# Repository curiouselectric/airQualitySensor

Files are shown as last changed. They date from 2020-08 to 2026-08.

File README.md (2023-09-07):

# airQualitySensor
This is a PCB and design for an air quality sensor unit using the [sensor.community](https://maps.sensor.community/) design

This is a PCB design (in KiCAD) and laser cut enclosure plate design to make an air quality sensor node for inclusion in the [sensor.community](https://maps.sensor.community/) global open environmental data platform .
I think the project is amazing and produced this design for a simplified, but robust DIY kit.

This is heavily based on these two open-source projects:

https://github.com/CivicLabsBelgium/influencair-pcb

https://github.com/Naesstrom/Airrohr-kit

The second link (by Erik Näsström) is a great design. I wanted to, very slightly, simplify this and produce a unit that does not need a 3d printer. I set about designing laser cut parts for this.

The PCB is very simple, but has been produced in the totally open-source PCB design package KiCAD.

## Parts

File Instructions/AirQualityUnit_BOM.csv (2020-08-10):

Reference | Item | Quantity | Value
C1 | Power supply buffer capacitor | 1 | 220uf
J1 | 2.1mm barrel jack power connector | 1 | 5V
J2 | 2 way screw terminal | 1 | 5V
J3 | ADC input pins | 0 | ADC_IN
J4 | ADS1115 ADC connector. NOT supplied! | 0 | ADS1115_ADC
J8 | Temperature and Humidity Sensor | 1 | BME280
J9 | 4 way Connector - Grove Wiring. NOT supplied! | 0 | I2C_1
J10 | 4 way Connector - Grove Wiring. NOT supplied! | 0 | I2C_2
J11 | 4 way Connector - Grove Wiring. NOT supplied! | 0 | I2C_3
J12 | Temperature and Humidity Sensor. NOT supplied! | 0 | DHT22
J13 | 5Way JST-XH 90 Connector for: Dust and particle sensor. | 1 | SDS011
J14,J15 | 15 way Header for NodeMCU | 2 | ESP_BO1, ESP_BO2
P1 | SMD USB connector. NOT supplied! | 0 | PWR
R1 | Used if DHT22 sensor used. NOT supplied! | 0 | 4k7
U1 | Programmed NodeMCU ESP8266 Unit. | 1 | NODEMCU
PCB | Circuit board for all sensors. | 1
SDS011 | Dust and Particle sensor | 1
USB Power Lead | 5m USB cable. | 1
Wire | 4 colours for connecting BME280 to PCB. | 4
Enclosure | Waterproof small encosure. Pre-cut holes. | 1
Baseplate | Laser Cut | 1
Rubber Seal | Laser Cut | 1
Side Plate | Laser Cut | 1
Insect Mesh | Small piece | 1
Gromit | For USB power lead | 1
Pipe | Small Pipe ID: 6mm OD 8mm - yellow | 1
Spacers 3mm | Hold SDS to PCB | 3
Spacers 20mm | Hold SDS to baseplate | 3
M3 screws 10mm | Hold PCB and Baseplate | 6
Self Tapping screws | Hold baseplate to enclosure | 4
M3 screws 20mm | Hold rubber seal and side plate | 4
M3 Nuts | Hold rubber seal and side plate | 4
M2 screws 20mm | Hold BME280 in place | 2
M2 Nuts | Hold BME280 in place | 2

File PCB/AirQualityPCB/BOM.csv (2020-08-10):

Reference | Value | Footprint | Datasheet
U1 | NODEMCU | REInnovationFootprint:NodeMCU_Amica_R2_FSILK
J13 | SDS011 | REInnovationFootprint:SIL-5_JST_5WAY_labelled | ~
J8 | BME280 | REInnovationFootprint:SIL-4_large_pad_BME280 | ~
J1 | 5V | REInnovationFootprint:DC_Power_2_1 | ~
J2 | 5V | REInnovationFootprint:SIL-2_screw_terminal | ~
P1 | PWR | REInnovationFootprint:USB_Micro-B_MOLEX_47642-0001
J5 | PCB | REInnovationFootprint:PCB_LuftDaten_70x70 | ~
J6 | LOGO_OSW | REInnovationFootprint:OSHW_logo_small_back | ~
J7 | LOGO_TCEC | CuriousElectric3:TCEC_Words_13mm | ~
J9 | I2C_1 | REInnovationFootprint:SIL-4_Grove_Labelled | ~
J11 | I2C_3 | REInnovationFootprint:SIL-4_Grove_Labelled | ~
J10 | I2C_2 | REInnovationFootprint:SIL-4_Grove_Labelled | ~
R1 | 4k7 | REInnovationFootprint:TH_Resistor_1 | ~
J12 | DHT22 | REInnovationFootprint:SIL-4_large_pad_DHT22 | ~
J4 | ADS1115_ADC | REInnovationFootprint:ADAFRUIT_ADS1115 | ~
J14 | ESP_BO1 | Connector_PinSocket_2.54mm:PinSocket_1x15_P2.54mm_Vertical | ~
J15 | ESP_BO2 | Connector_PinSocket_2.54mm:PinSocket_1x15_P2.54mm_Vertical | ~
J16 | LOGO_LUFTDATEN | CuriousElectric3:sensorcommunity | ~
J17 | LOGO_AirRohr | CuriousElectric3:logo_conversion | ~
J18 | LOGO_TCEC | CuriousElectric3:2019_011_16_CuriousElectricCompany_Logo_Round_Logo_No_words_KiCAD_10mm_PCBLogo | ~
C1 | 100uf | REInnovationFootprint:C_Radial_D6.3_L11.2_P2.5 | ~
J3 | ADC_IN | REInnovationFootprint:PinSocket_1x12_P2.54mm_Vertical_Labelled | ~

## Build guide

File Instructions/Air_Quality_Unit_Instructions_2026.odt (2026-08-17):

| Air Quality Unit Build Instructions

Date: | 17/09/2026 | Version: | 1.3 | By: | Matt Little

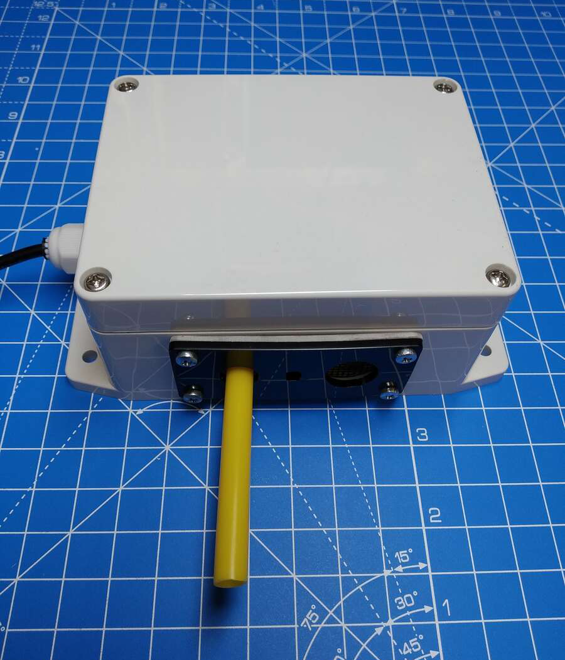
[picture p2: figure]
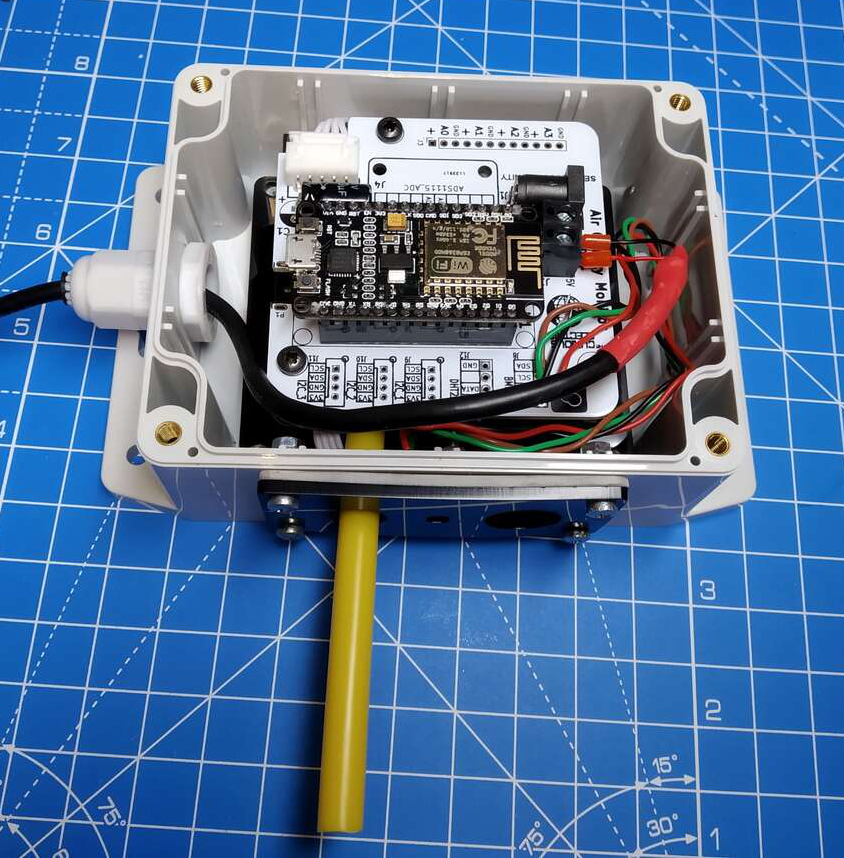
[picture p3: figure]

Build your own air quality monitor and contribute to the https://maps.sensor.community worldwide air quality monitoring project. Civil Tech in action!

This kit contains all you need to set up your own online air quality monitoring unit. This records the PM2.5 and PM10 particulate data, along with temperature and humidity. This is sent (via your Wi-Fi connection) to the sensor.community platform.

In building and installing this equipment you are helping monitor local and global air quality and provide results to a growing network of civil technology sensor units!

The unit uses the SDS011 dust and particulate sensor, along with a BME280 temperature and humidity sensor. These are interfaced with an ESP8266 Wi-Fi enabled microcontroller.

Additional PCB connections can be made to add more sensors in the future.

Note: This kit contains all hardware required to set up your sensor unit. You will need a local wifi connection. You will need to install in a location which can connect to that network.

This kit requires soldering, some hardware construction and setting up an online sensor.community account and sensor node. This should take in the region of 2-4 hours to build.

This kit relies upon the sensor.community platform. Curious Electric use their firmware and do not have any input to the software side of the project.

Parts included:

| | Baseplate | 4 x self-tapping screws | | PCB | SDS011 Dust Sensor

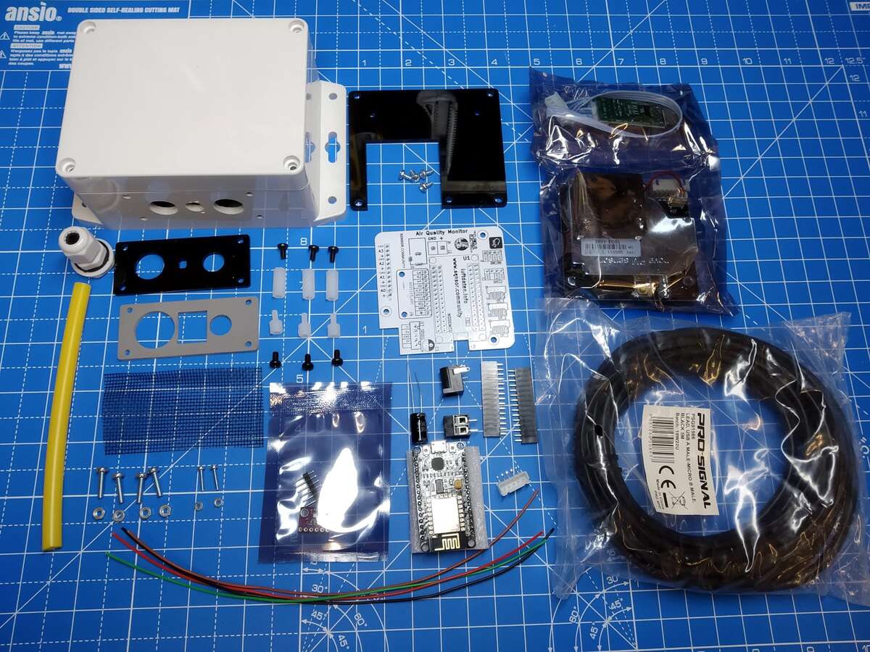
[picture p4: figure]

Enclosure (pre-cut holes)
| | | | | | | | Power Jack
| | | | | | | | 2 x 15way Header Pins
Compression Gland
Sensor Plate | | | | | | | | 220uf Capacitor
| | | | | | | | Screw Terminals
Rubber Gasket | | | | | | | | USB lead (5m)
M3 Hex Spacers: 3 x 6mm & 3 x 15mm
6 x M3 6mm screws | | | | | | | | 5 Way JST-XH Socket
8mm Pipe | M3 fixings 12mm x 4 | M2.5 fixings 12mm x 2 | | Mesh | BME280 (in bag – pins not needed) | Node MCU (ESP2866)

Parts list:

Item | Ref | | Item | Ref
Power supply buffer capacitor. 220uf | C1 | | Dust and Particle sensor | SDS011
2.1mm barrel jack power connector | J1 | | 5m USB cable. | USB Power Lead
2 way screw terminal | J2 | | Waterproof small enclosure. Pre-cut holes. | Enclosure
ADC input pins NOT supplied/needed! | J3 | | Laser Cut | Baseplate
ADS1115 ADC connector. NOT supplied! | J4 | | Laser Cut | Rubber Seal
BME280. Temperature and Humidity Sensor | J8 | | Laser Cut | Side Plate
4 way Connector - Grove Wiring. NOT supplied! | J9, J10, J11 | | Small piece | Insect Mesh
Temperature and Humidity Sensor. NOT supplied! | J12 | | For USB power lead | Compression Gland
5 Way JST-XH 90 Connector for SDS sensor. | J13 | | Small piece of Pipe 6mm OD 8mm - yellow | Pipe
2 x 15 way Header for NodeMCU | J14, J15 | | Hold SDS011 sesnsor to PCB. M3 Hex Spacers. | 3 x Hex Spacers 6mm
SMD USB connector. NOT supplied! | P1 | | Hold SDS011 sesnsor to PCB. M3 Hex Spacers. | 3 x Hex Spacers 15mm
4k7 ohm. For DHT22 sensor. NOT supplied! | R1 | | Hold PCB and Baseplate | 6 x M3 screws 6mm
NodeMCU ESP8266 Unit. Programmed with airRohr software. | U1 | | Hold baseplate to enclosure | Self Tapping screws
Printed Circuit Board. | PCB | | Hold rubber seal and side plate | 4 x M3 screws 12mm
4 x colour cable for connecting BME280 to PCB. 10cm long. | Cable | | Hold rubber seal and side plate | 4 x M3 Nuts
240V AC UK Plug USB PSU 1.2A | PSU | | Hold BME280 in place | 2 x M2.5 screws 12mm
| | | Hold BME280 in place | 2 x M2.5 Nuts

Tools required:

You may also need some scissors.

Hardware Instructions:

Step: 1 | Solder PCB

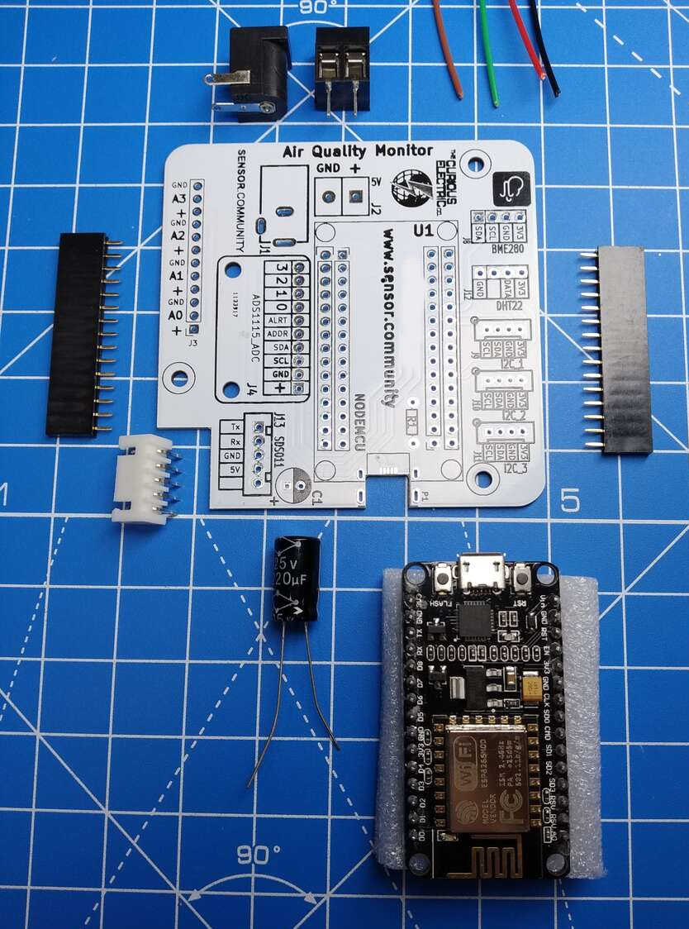
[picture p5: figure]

First we need to solder the components to the printed circuit board (PCB).

There are 6 components and 4 wires to solder.

Note: J1, J2 and J13 need to be pointing away from the edge of the PCB when fitted.

Fit J1 (barrel jack socket) and solder.

Fit J2 (screw terminals) and solder.

Fit J13 (JST-XH 5 way right angle connector) and solder.

Fit the two rows of header pins onto the pins of the NodeMCU. This can then be put in the holes marked for U1.

Check the orientation of the NodeMCU – the USB port should be towards the edge of the PCB.

The header pins can then be soldered to the PCB. Using the NodeMCU during soldering keeps the pins in place.

Next solder the polarised capacitor. Ensure correct orientation of these components.

The negative lead on the capacitor is marked with a white strip. The positive lead is slightly longer than the negative. Align the positive lead with the + sign and the negative lead with the black PCB marking.

Value | Ref | Marking
220uf Capacitor | C1 | 25V 220uf

This component is put into position then bent to lie flat on the PCB. Then solder it. This is required to ensure the lid fits on the enclosure.

Ensure sockets are point away from the edge of the PCB, as the cables will enter from the edge.

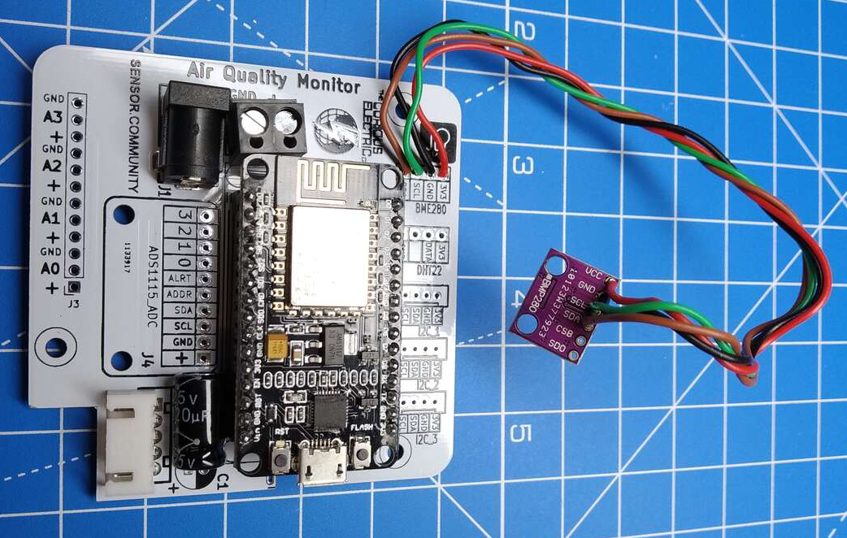
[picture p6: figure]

Using the four wires we need to solder the main PCB and connect to the BME280 sensor. Solder these wires so they come out on the labelled side of the sensor (as per photo).

Ensure USB pointing out, towards the PCB edge

There are four connections to make:

PCB BME280

+3.3V – Use Red wire. - VCC

GND – Use Black wire. - GND

SDA – Use either colour. - SDA

SCL – Use either colour. - SCL

The BME280 PCB is labelled with the same connections. Solder the matching names to the BME280.

Step: 2 | Add spacers to dust sensor

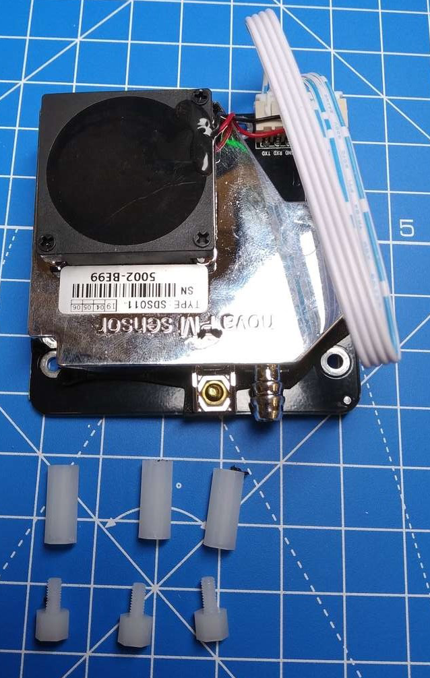
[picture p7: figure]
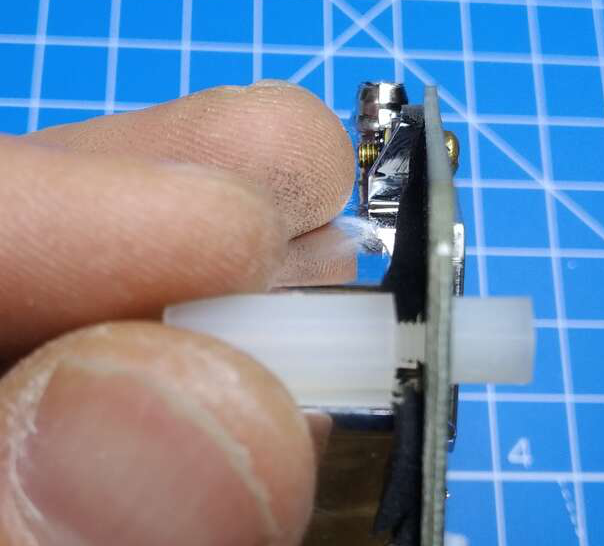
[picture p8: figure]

Take the SDS011 unit and cable from its package. (Note: There is a USB to serial converter in the package, if you would like to directly connect to the sensor from a computer, but that is not needed for this project) Use the 3 x 6mm M3 hex spacers (with thread sticking out) and the 3 x 15mm M3 hex spacers and connect through the three mouthing holes on the dust sensor. The longer (15mm) hex spacers should go on the side with the sensor (shiny box and fan), while the shorter spacers go on the PCB side of the sensor.

Step: 3 | Mount sensor to baseplate.

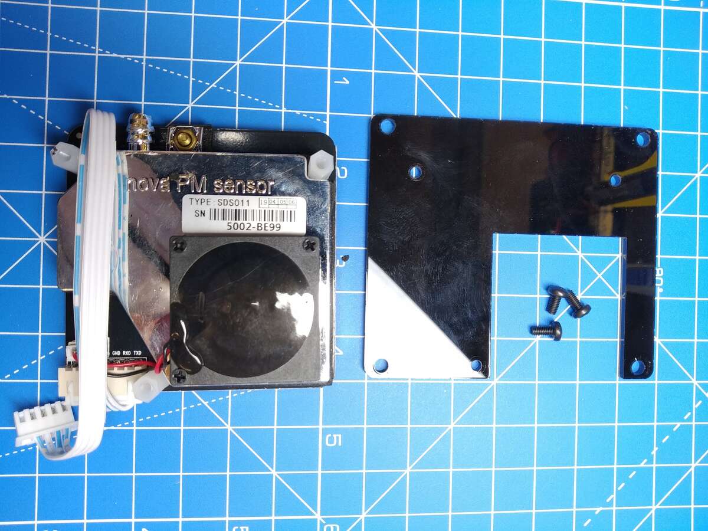
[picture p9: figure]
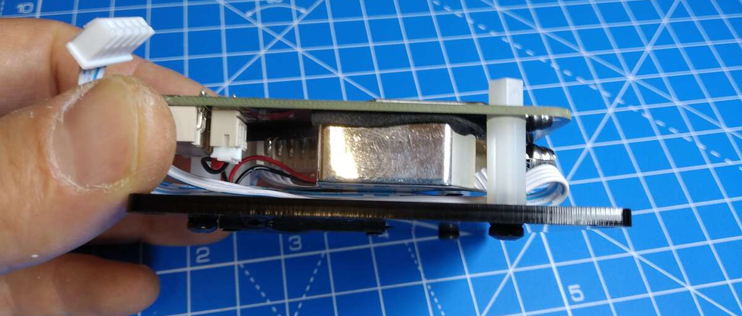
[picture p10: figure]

| | The SDS011 is mounted on the baseplate with the 20mm spacers towards the baseplate. The fan fits into the cut-out of the baseplate. Use 3 x M3 6mm machine screws to hold the sensor to the baseplate.

Step: 4 | Mount PCB to Sensor

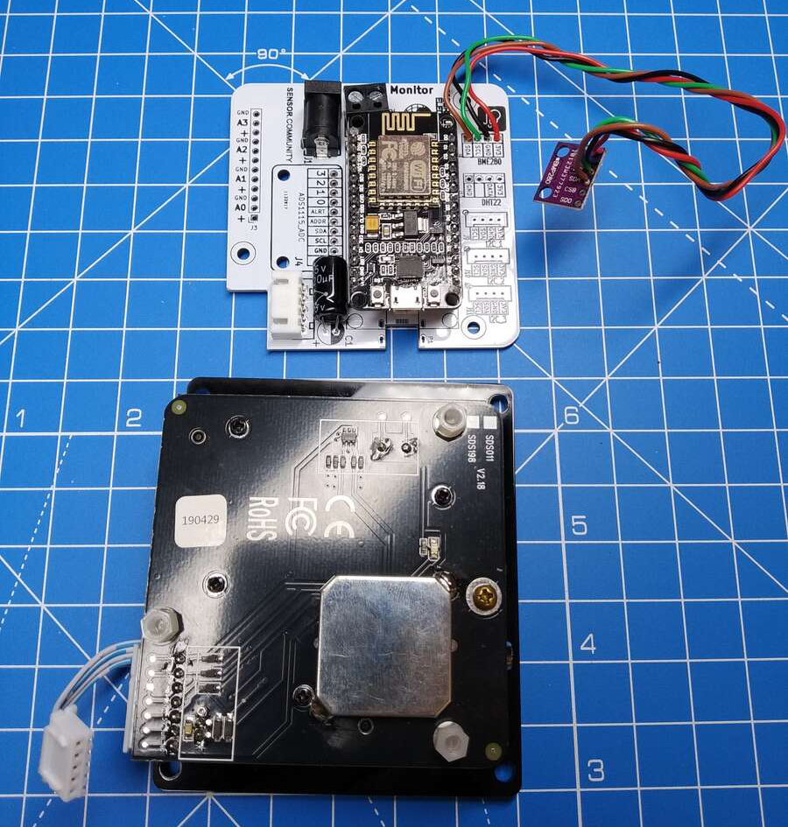
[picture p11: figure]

Mount the PCB to the top of the sensor. Use 3 of the M3 6mm machine screws to hold the PCB to the shorter hex spacers on the sensor. Use the white cable that comes with the SDS011 dust sensor to the PCB. The cable might need to be folded under to keep it out of the way.

Step: 5 | Add compression gland

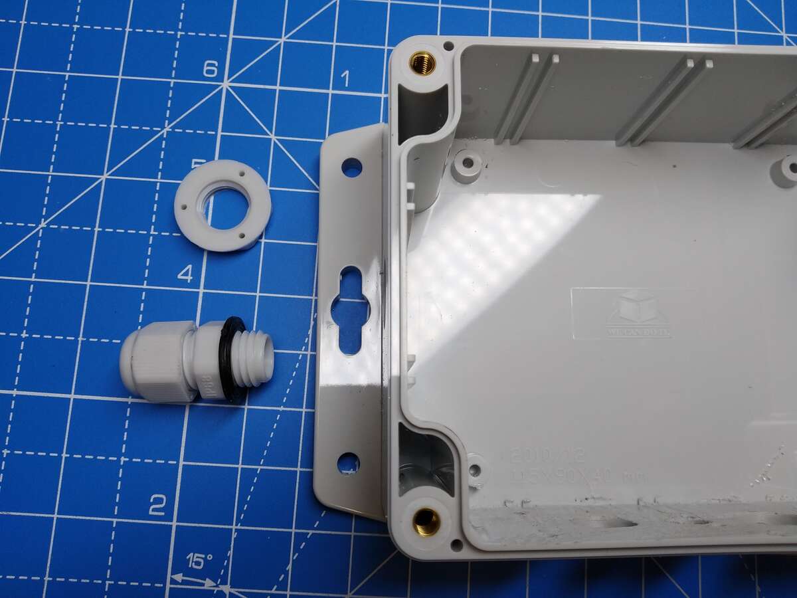
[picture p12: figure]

| | Mount the compression gland through the hold on the side of the enclosure. The enclosure is slightly thick for the gland, but if the nut is turned around, so the wide lip faces away from the gland, then it should grip the screw thread. Or the black rubber ring can be removed, although it will have slightly less waterproofing.

Step: 6 | Mount BME280 temperature and humidity sensor

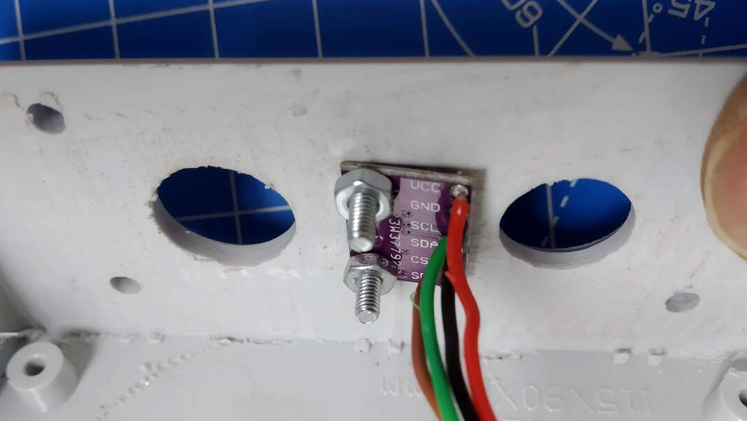
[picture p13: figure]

Use the 2 x M2.5 screws and nuts to mount the BME280 sensor PCB into the middle hole (hole with two smaller holes next to it) so that the small metal sensor unit shows through the larger hole in the middle.

Step: 7 | Cut mesh

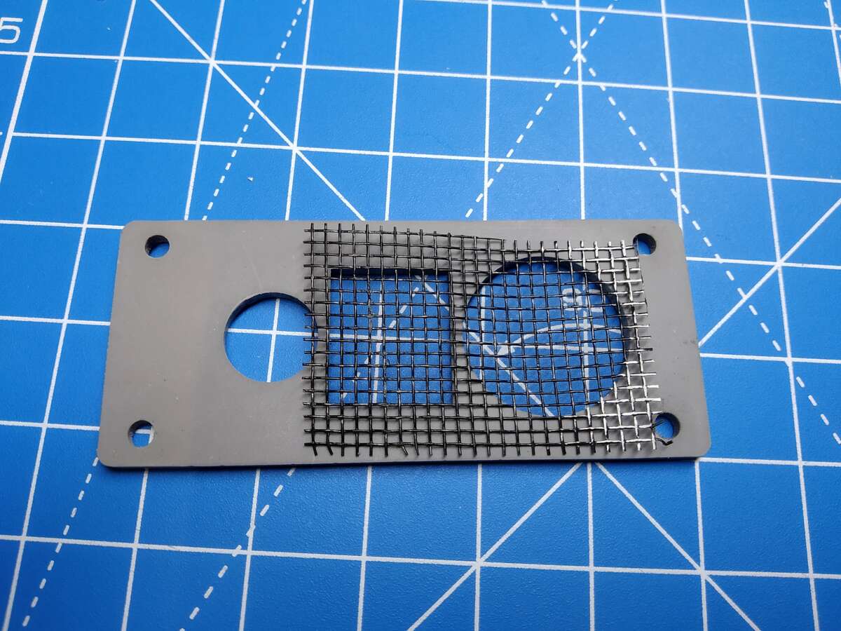
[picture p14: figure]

| | Cut the piece of mesh to a size that covers the larger round and the middle rectangular hole on the rubber gasket.

Step: 8 | Add mesh, gasket and sensor plate

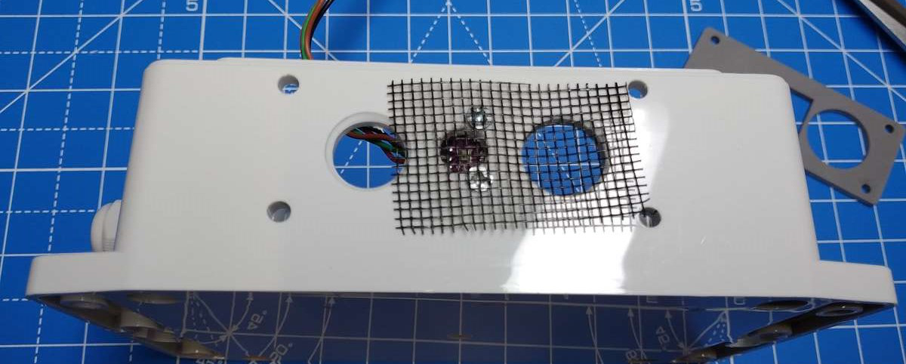
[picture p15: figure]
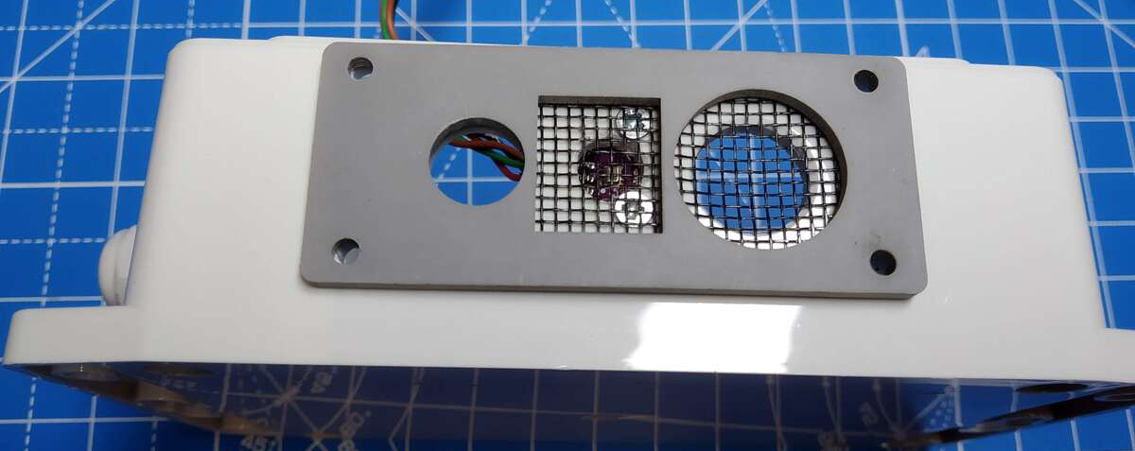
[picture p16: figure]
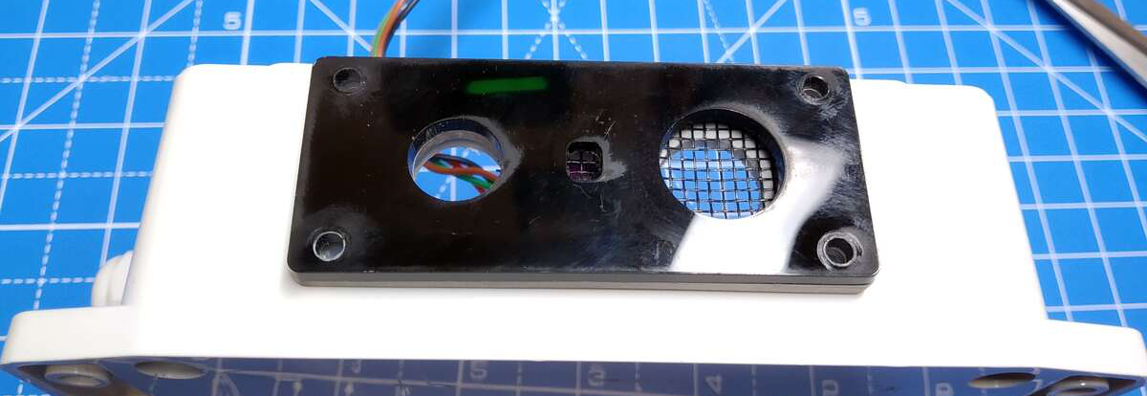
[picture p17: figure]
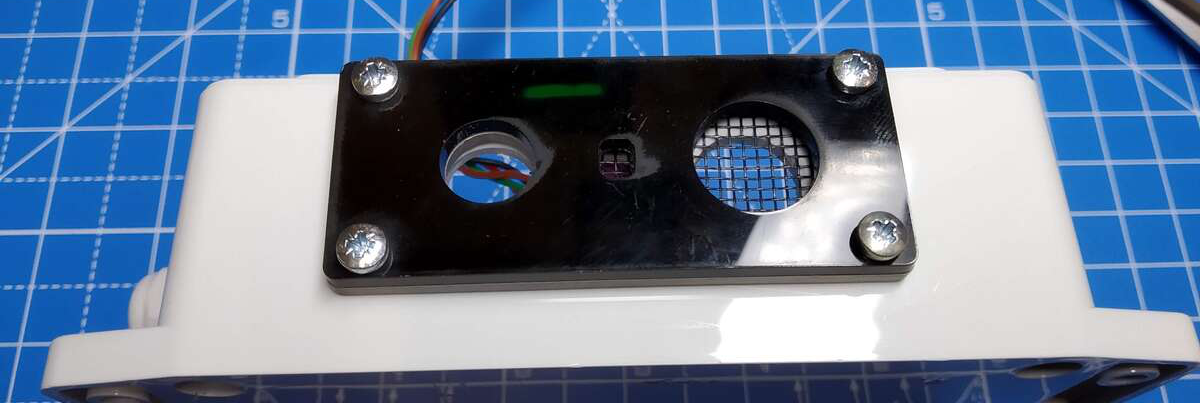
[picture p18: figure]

The mesh is held in place with the rubber gasket and the plastic outer plate. Fit the mesh first, then the rubber gasket, then the 3mm acrylic output plate. Use the 4 x M3 12mm screws and nuts to hold these in place onto the enclosure.

Step: 9 | Mount baseplate into enclosure.

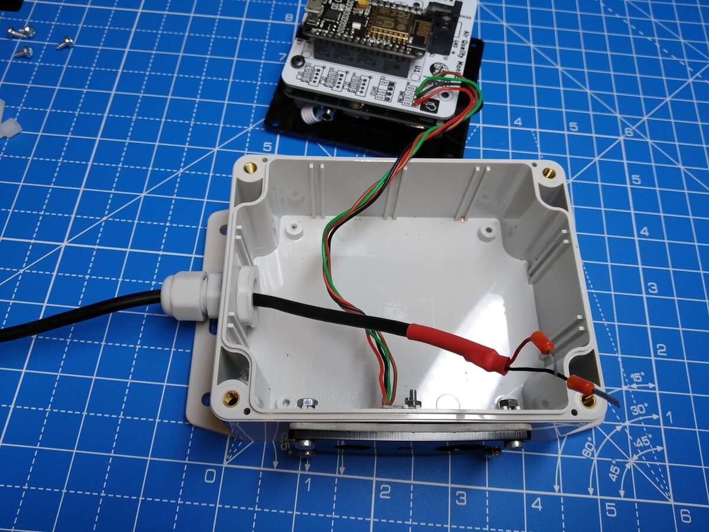
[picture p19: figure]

| | Put the USB power cable through the compression gland, with the power terminals through into the enclosure. It’s easiest to add the USB lead now, or else it’s more difficult with the sensor/baseplate in place. Fold the USB cable out of the way. Fit the baseplate (with sensor and PCB) into the enclosure. Use the 4 x self-tapping screws to hold the baseplate to the base of the enclosure. I only use two of the self-tapping screws, as that is enough to hold the baseplate. Ensure no cables are pinched or trapped.

Step: 10 | Add the sensor tube

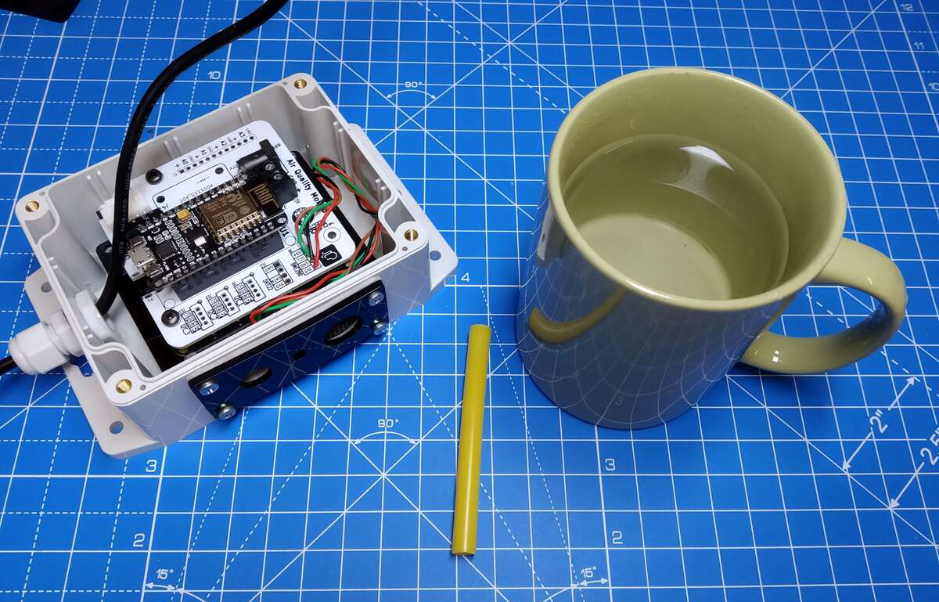
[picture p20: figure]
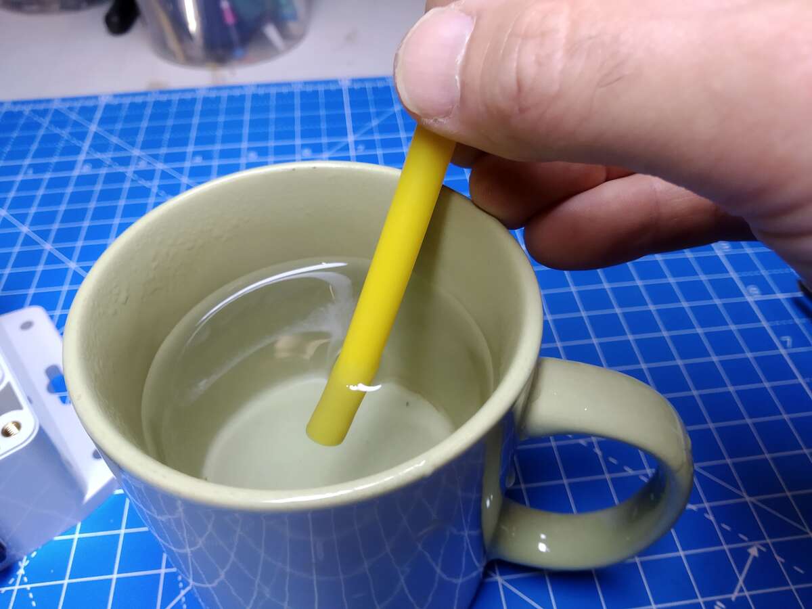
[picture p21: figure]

The yellow plastic tube is used as the intake for the sensor. The tube is mounted through the smaller round hole on the outer sensor plate through and onto the round intake for the SDS011. To make this a bit easier, warm the yellow tube in some boiling water for a few minutes. Warning: Take care! This can be very hot! Push the intake tube through the smaller hole and onto the intake for the SDS011 sensor. You may need to rotate slightly as you push. This will be quite a tight fit.

Step: 11 | Wire up power supply

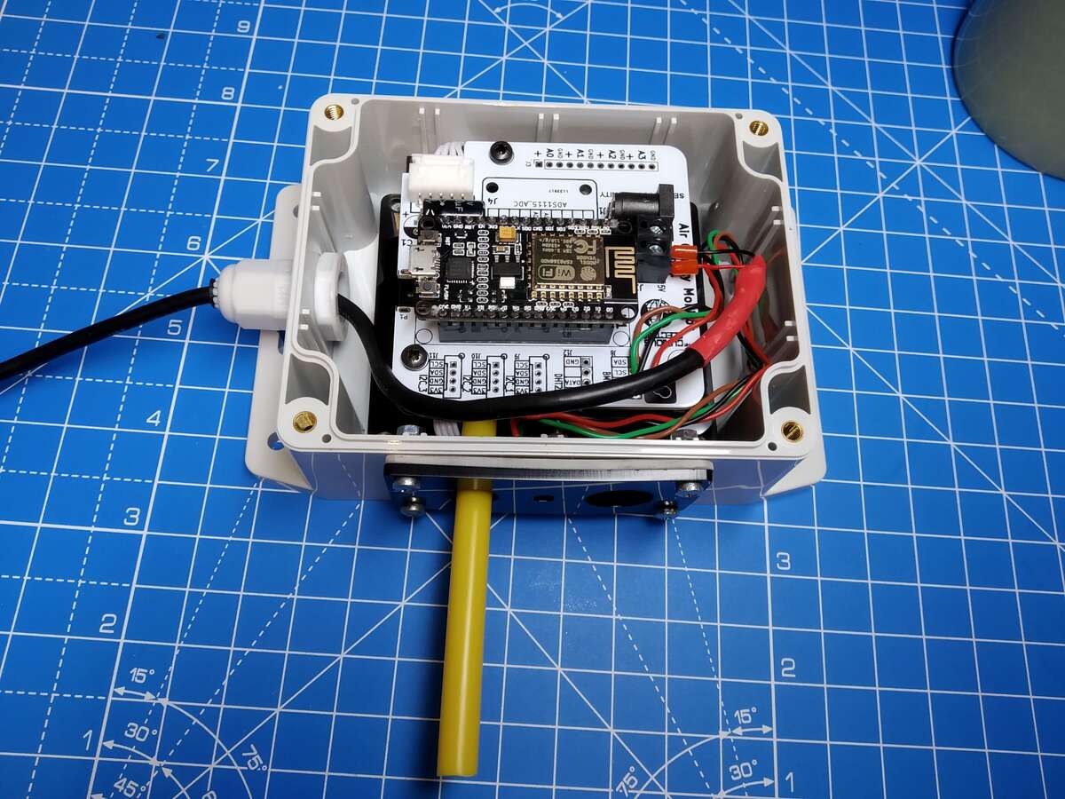
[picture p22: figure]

| | Ensure the cables fit into the enclosure. Wire up the USB power supply cable into the unit, with the red wire into the “+5V” screw terminal and the black wire into the “GND” terminal. If you plug the other end into the USB power supply unit then the blue light on the NodeMCU should briefly flash.

Step: 12 | Fit lid to enclosure

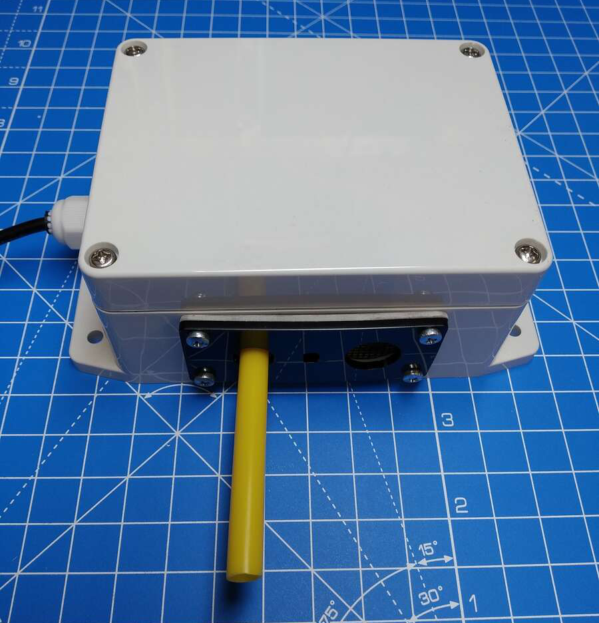
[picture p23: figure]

The lid needs the sealing strip mounted around the lid. Then fit the 4 x enclosure screws through the lid holes and close the unit up.

Step: 13 | Build is finished!
| | Have a nice cup of tea.

Set-Up Instructions:

Step: 1 | Register and set-up your sensor node

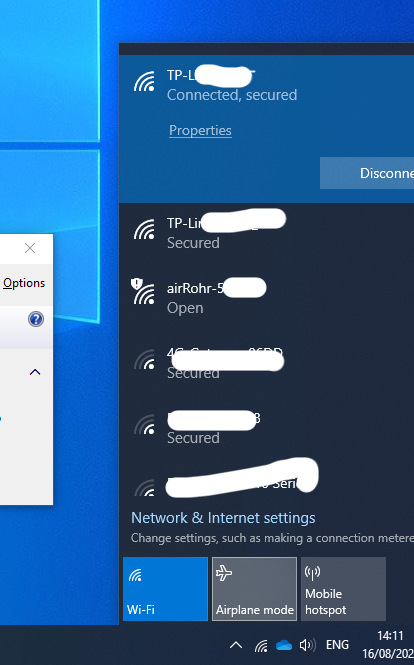
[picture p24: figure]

Note: These instructions follow the information given by the air-rohr/sensor.coummunity information given here:

https://sensor.community/en/sensors/airrohr/

Power up the sensor node using the USB lead.

Wait a few moments and refresh your Wi-Fi channel list (Note: this might take a while and require a few refreshes of the list)

There should be a Wi-Fi connection called “airRohr-123456”, where 123456 is an ID number.

Write down the ID number for future reference.

Connect to the airRohr Wi-Fi connection.

It should open automatically, but if not: Using your browser, go to http://192.168.4.1/

There will be a lot of options on that page. Some is written in German (as this was originally a German project).

Click on your network and enter in the network password.

Click on the “English” language option (or others for different language options). (Update: This now starts in English automatically)

Un-click the DHT22 sensor.

Click on the BME280 sensor.

Click on the RED “Speichern und neu starten” or “Save and Re-start” button at the bottom of the page. This will save the data and restart the node.

Re-connect your computer to your normal Wi-Fi connection.

Step: 2 | Register the sensor with sensor.community

Go to: https://devices.sensor.community/

You will need to register an account with this site.

Then click on: “My Sensors”

The click on “Register a new Sensor”

Follow the sensor registration page – you will need the device ID you wrote down in the previous step.

Change the hardware configuration so that the first sensor is the SDS011 (on pin 1) and the BME280 (on pin 11). The pin number change automatically when you click on the correct sensor. To see the pin numbers you may need to click on the “Advanced” tab (as pin numbers are hidden to keep it simpler). The pin numbers are the default values, so should not need changing.

Enter the location and any other details required and then “Save settings”

You can then check under your “My Sensors” list to check it is there.

Wait at least 30mins (or more!) and then re-check the “My Sensors” list.

Click on ‘Data’ and you should be able to see the latest data that has been uploaded.

Step: 3

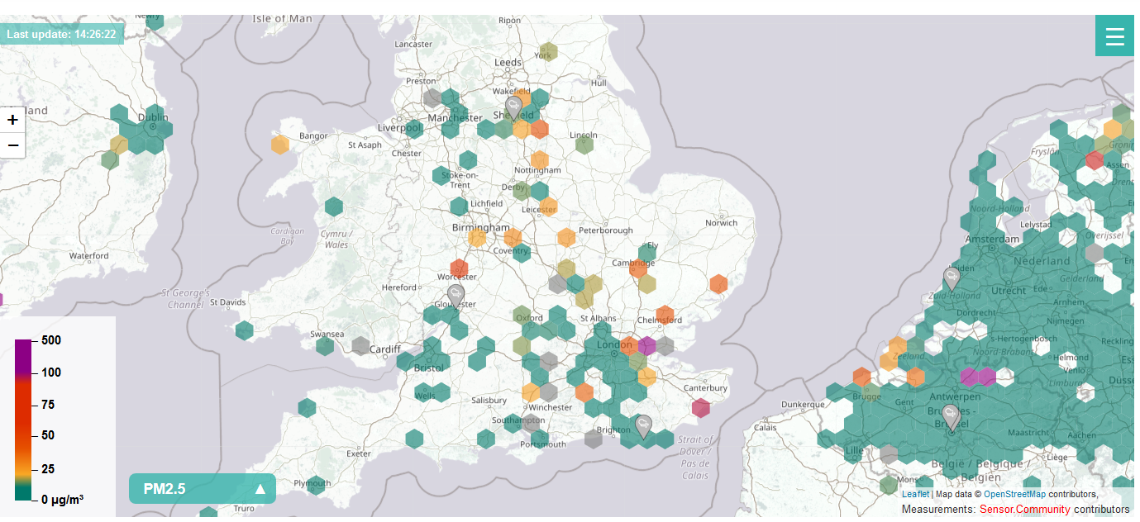
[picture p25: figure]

| | Congratulations! You are now sending data to the sensor.community site and you should be able to see you sensor data on the world map!

This project full build, PCB and instructions can be found here:

https://github.com/curiouselectric/airQualitySensor

Contact details:

We would like you to be happy with this kit. If you are not happy for any reason then please contact us and we will help to sort it out.

Please email hello@curiouselectric.co.uk with any questions or comments.

Please tweet us at @curiouselectric

If any parts are missing from your kit then please email hello@curiouselectric.co.uk with details and, if possible, when and where the kit was purchased.

More technical information can be found via www.curiouselectric.co.uk

This kit has been designed and produced by:

The Curious Electric Company

hello@curiouselectric.co.uk

www.curiouselectric.co.uk

# History

This kit is based upon lots of work by others especially:

- https://sensor.community/en/
- https://github.com/CivicLabsBelgium/influencair-pcb
- https://github.com/Naesstrom/Airrohr-kit

Circuit Schematic

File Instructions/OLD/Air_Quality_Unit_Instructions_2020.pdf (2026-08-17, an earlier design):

## Air Quality Unit Build Instructions

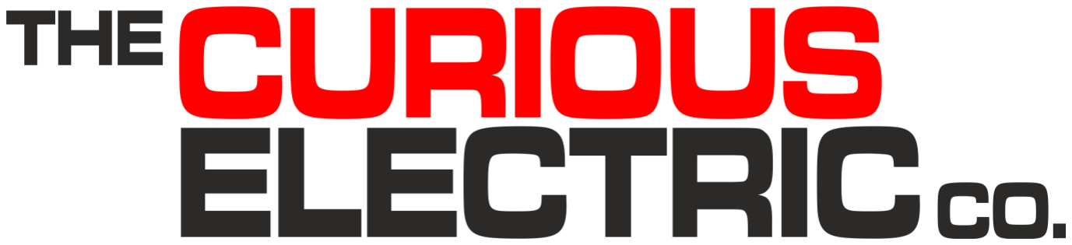
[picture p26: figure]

Date: | 07/09/2023 | Version: | 1.2 | By: | Matt Little

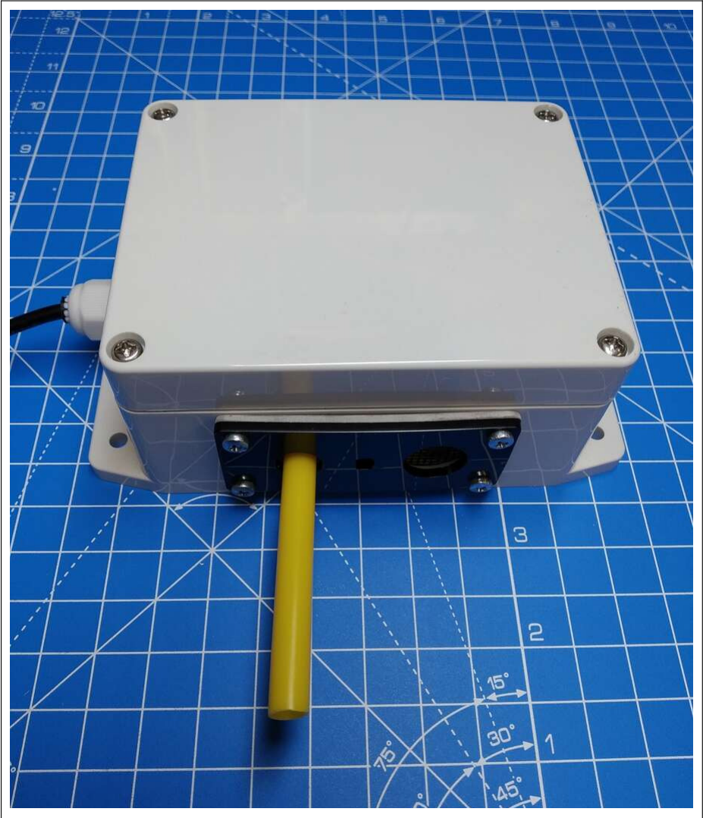
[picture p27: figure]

Build your own air quality monitor and contribute to the https://maps.sensor.community worldwide air quality monitoring project. Civil Tech in action!

This kit contains all you need to set up your own online air quality monitoring unit. This records the PM2.5 and PM10 particulate data, along with temperature and humidity. This is sent (via your Wi-Fi connection) to the sensor.community platform.

In building and installing this equipment you are helping monitor local and global air quality and provide results to a growing network of civil technology sensor units!

The unit uses the SDS011 dust and particulate sensor, along with a BME280 temperature and humidity sensor. These are interfaced with an ESP8266 Wi-Fi enabled microcontroller.

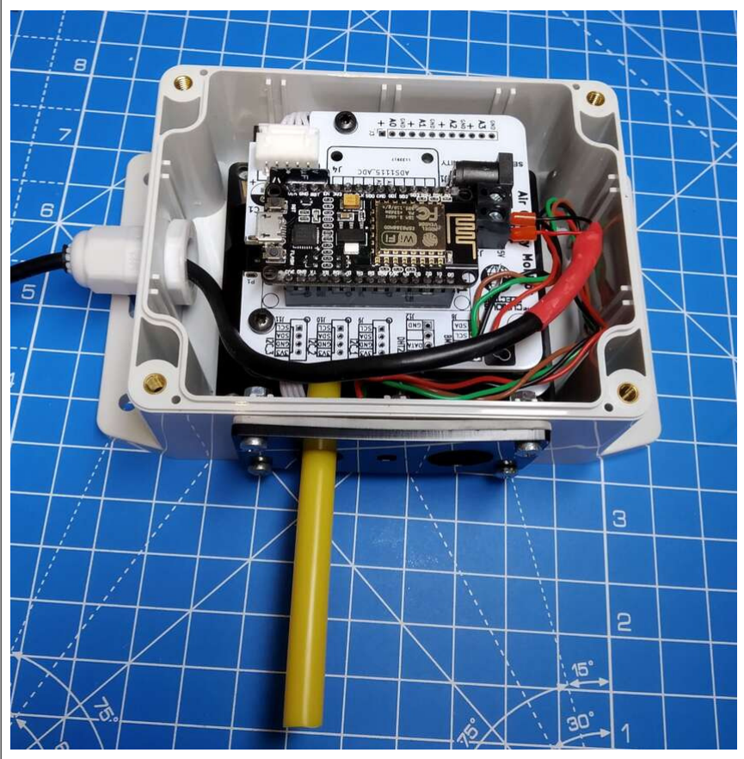
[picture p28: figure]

Additional PCB connections can be made to add more sensors in the future.

Note: This kit contains all hardware required to set up your sensor unit. You will need a local wifi connection. You will need to install in a location which can connect to that network.

This kit requires soldering, some hardware construction and setting up an online sensor.community account and sensor node. This should take in the region of 2-4 hours to build.

This kit relies upon the sensor.community platform. Curious Electric use their firmware and do not have any input to the software side of the project.

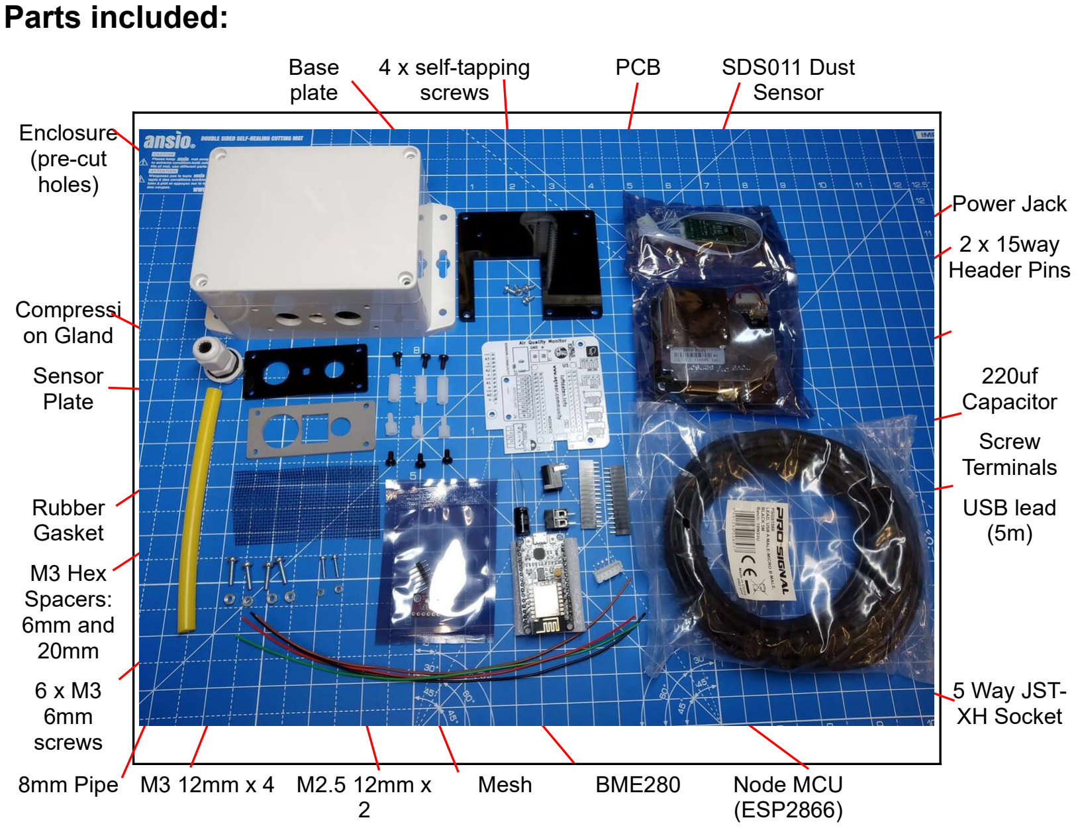
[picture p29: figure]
Parts included:; Base plate; 4 x self-tapping screws; PCB; SDS011 Dust; Sensor; Enclosure (pre-cut holes); Power Jack; 2 x 15way Header Pins; Compressi on Gland; Sensor Plate; 220uf Capacitor; Screw Terminals; Rubber Gasket; USB lead (5m); M3 Hex Spacers: 6mm and 20mm; 6 x M3 6mm screws; 5 Way JST- XH Socket; 8mm Pipe M3 12mm x 4 M2.5 12mm x 2; Mesh; BME280; Node MCU; (ESP2866)

Parts list:

Item | Ref | Item | Ref
Power supply buffer capacitor. 220uf | C1 | Dust and Parcle sensor | SDS011
2.1mm barrel jack power connector | J1 | 5m USB cable. | USB Power Lead
2 way screw terminal | J2 | Waterproof small enclosure. Pre-cut holes. | Enclosure
ADC input pins | J3 | Laser Cut | Baseplate
ADS1115 ADC connector. NOT supplied! | J4 | Laser Cut | Rubber Seal
BME280. Temperature and Humidity Sensor | J8 | Laser Cut | Side Plate
4 way Connector - Grove Wiring. NOT supplied! | J9, J10, J11 | Small piece | Insect Mesh
Temperature and Humidity Sensor. NOT supplied! | J12 | For USB power lead | Compression Gland
5 Way JST-XH 90 Connector for SDS sensor. | J13 | Small Pipe ID: 6mm OD 8mm -yellow | Pipe
15 way Header for NodeMCU | J14,J15 | Hold SDS to PCB. M3 Hex. | Hex Spacers 3mm
SMD USB connector. NOT supplied! | P1 | Hold SDS to baseplate. M3 Hex. | Spacers 20mm
4k7 ohm. For DHT22 sensor. NOT supplied! | R1 | Hold PCB and Baseplate | M3 screws 6mm
Programmed with airRohr so?ware. NodeMCU ESP8266 Unit. | U1 | Hold baseplate to enclosure | Self Tapping screws
Printed Circuit Board. | PCB | Hold rubber seal and side plate | M3 screws 12mm
4 colour cable for connecng BME280 to PCB. 10Cm long. | Cable | Hold rubber seal and side plate | M3 Nuts
240V AC UK Plug USB PSU 1.2A | PSU | Hold BME280 in place | M2.5 screws 12mm
| | Hold BME280 in place | M2.5 Nuts

Tools required:

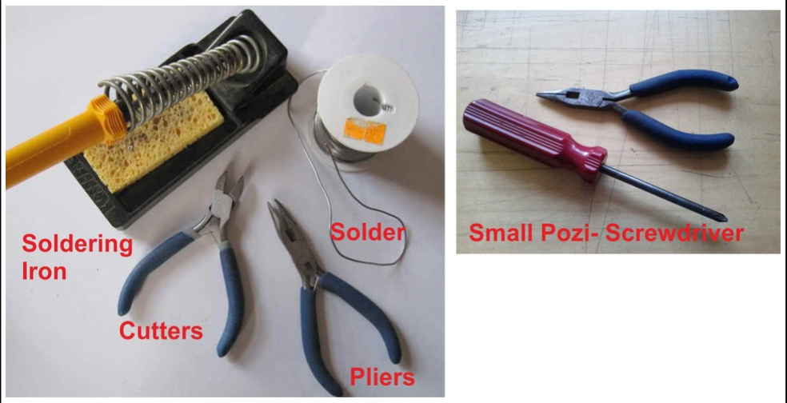
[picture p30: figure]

You may also need some scissors.

Hardware Instructions:

Step: 1 | Solder PCB
First we need to solder the components to the printed circuit board (PCB).
There are 6 components and 4 wires to solder.

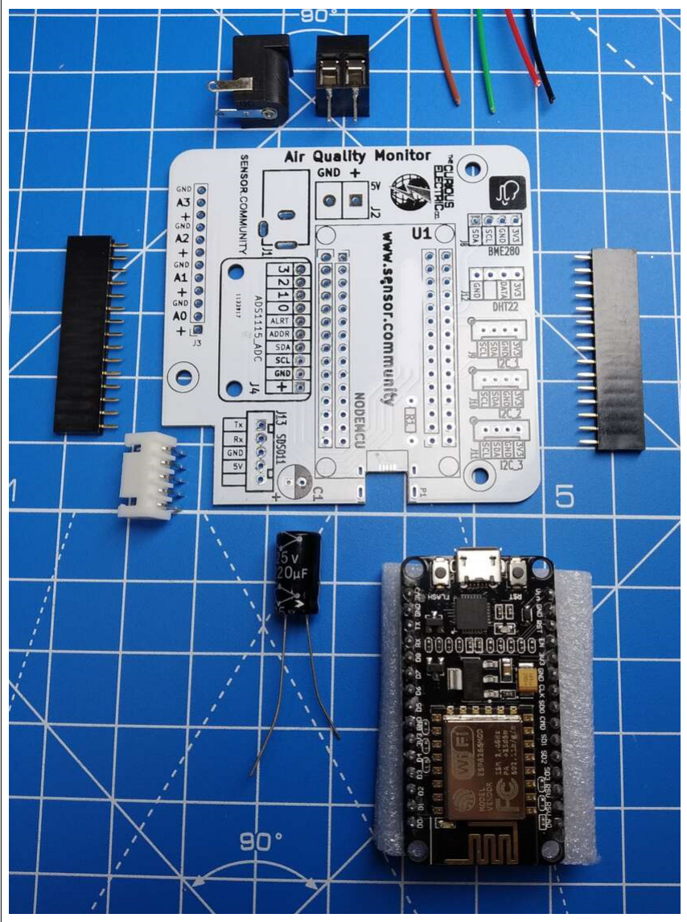
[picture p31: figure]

Fit J1 (barrel jack socket) and solder.
Fit J2 (screw terminals) and solder.
Fit J13 (JST-XH 5 way right angle connector) and solder.

Fit the two rows of header pins onto the pins of the NodeMCU. This can then be put in the holes marked for U1.
Check the orientation of the NodeMCU – the USB port should be towards the edge of the PCB.
The header pins can then be soldered to the PCB. Using the NodeMCU during soldering keeps the pins in place.

Next solder the polarised capacitor. Ensure correct orientation of these components. The negative lead is marked with a white strip. The positive lead is slightly longer than the negative. Align the positive lead with the + sign and the negative lead with the white PCB marking.
Value | Ref | Marking
220uf Capacitor | C1 | 25V 220uf
This component is put into position then bent to lie flat on the PCB. Then solder it. This is required to ensure the lid fits on the enclosure.

Using the four wires we need to solder the main PCB and connect to the BME280 sensor. There are four connections to make:
PCB | BME280
+3.3V – Use Red wire. - VCC
GND – Use Black wire. - GND SDA – Use either colour. - SDA
SCL – Use either colour. - SCL
The BME280 PCB is labelled with the same connections. Solder the matching names to the BME280.

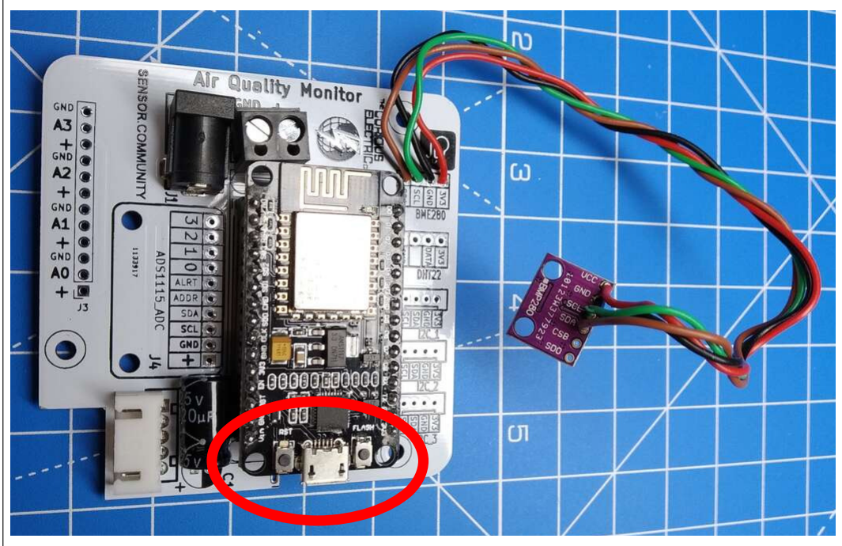
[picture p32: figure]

Ensure USB pointing out,
towards the PCB edge

Step: 2 Add spacers to dust sensor Take the SDS011 unit from its package. There is a USB to serial converter in the package, if you
would like to directly connect to the sensor from a computer, but that is not needed for this project.

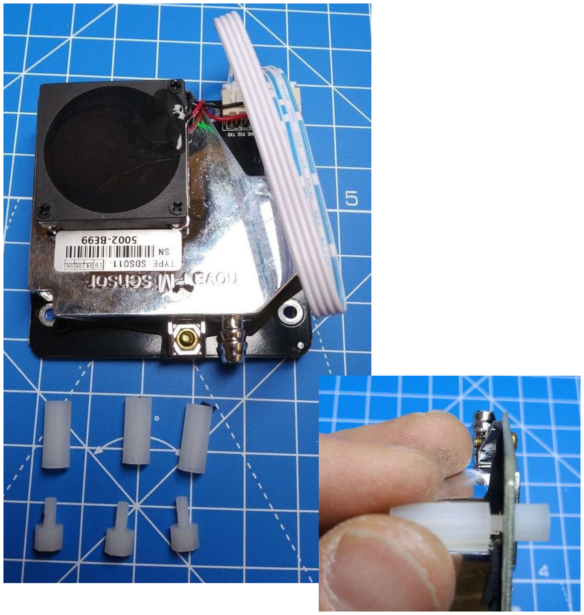
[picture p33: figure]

Use the 3 x 6mm M3 Hex spacers (with thread sticking out) and the 3 x 20mm M3 Hex spacers and connect through the three mouthing holes on the dust sensor. The longer (20mm) hex spacers should go on the side with the sensor (shiny box and fan), while the shorter spacers go on the PCB side of the sensor.

Step: 3 Mount sensor to baseplate. The SDS011 is mounted on the baseplate with the 20mm
spacers towards the baseplate. The fan fits into the cut-out of the baseplate.

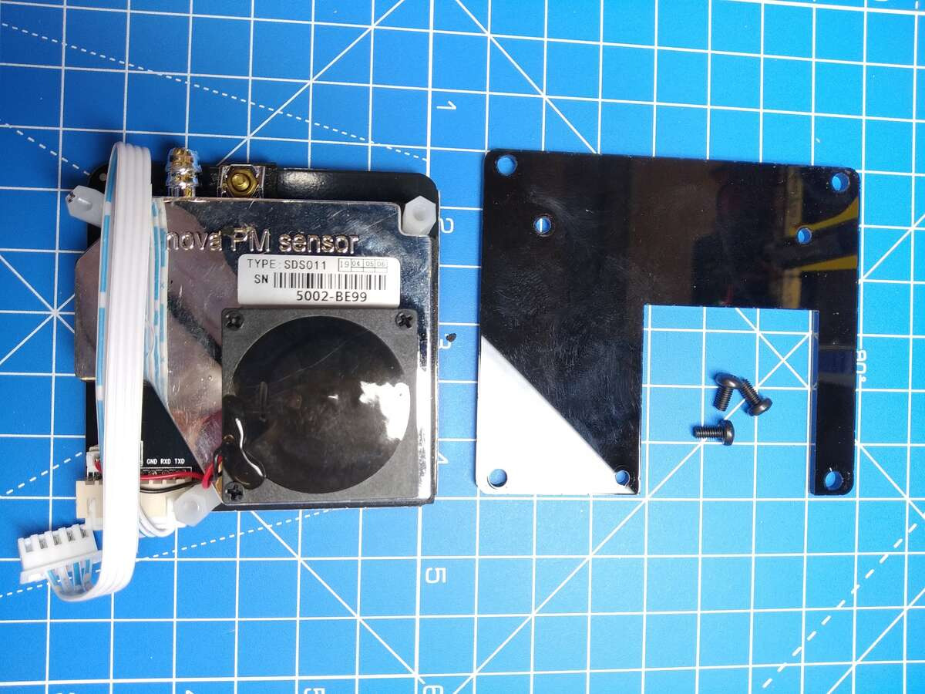
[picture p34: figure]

Use 3 x M3 6mm machine
screws to hold the sensor to the baseplate.

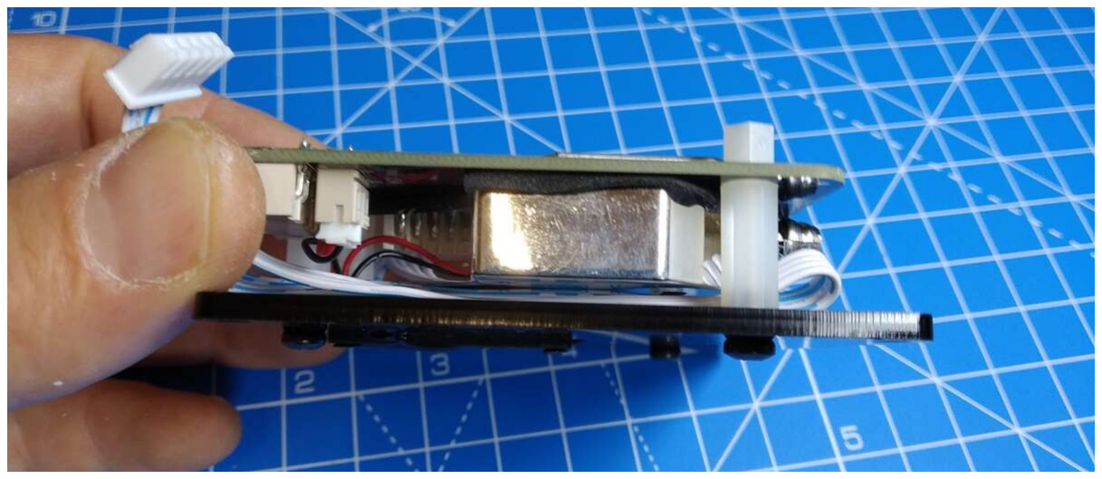
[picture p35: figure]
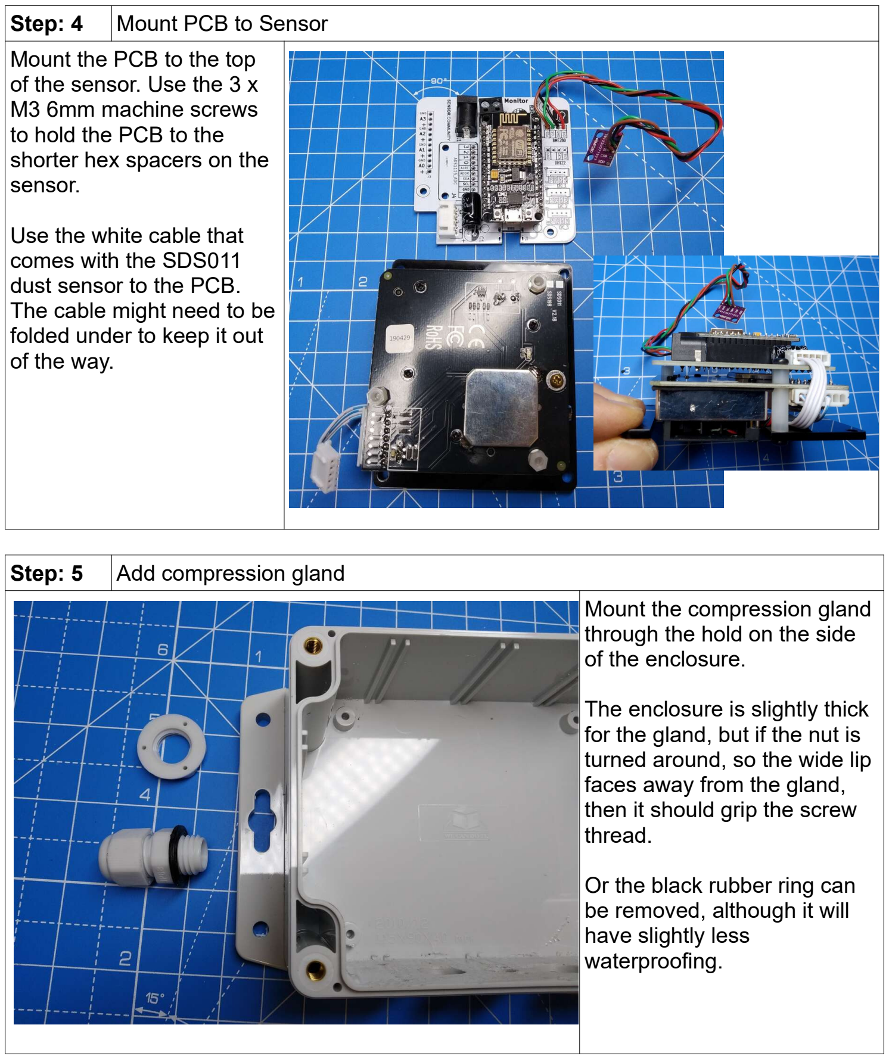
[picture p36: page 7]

Step: 4 Mount PCB to Sensor Mount the PCB to the top
of the sensor. Use the 3 x
M3 6mm machine screws
to hold the PCB to the
shorter hex spacers on the sensor.

Use the white cable that
comes with the SDS011
dust sensor to the PCB.
The cable might need to be folded under to keep it out of the way.

Step: 5 Add compression gland Mount the compression gland through the hold on the side of the enclosure.

The enclosure is slightly thick for the gland, but if the nut is turned around, so the wide lip faces away from the gland, then it should grip the screw thread.

Or the black rubber ring can be removed, although it will have slightly less
waterproofing.

Step: 6 | Mount BME280 temperature and humidity sensor
Use the 2 x M2.5 screws and nuts to mount the BME280 sensor PCB into the middle hole (hole with two smaller holes next to it) so that the small metal sensor unit shows through the larger hole in the middle.
Step: 7 | Cut mesh

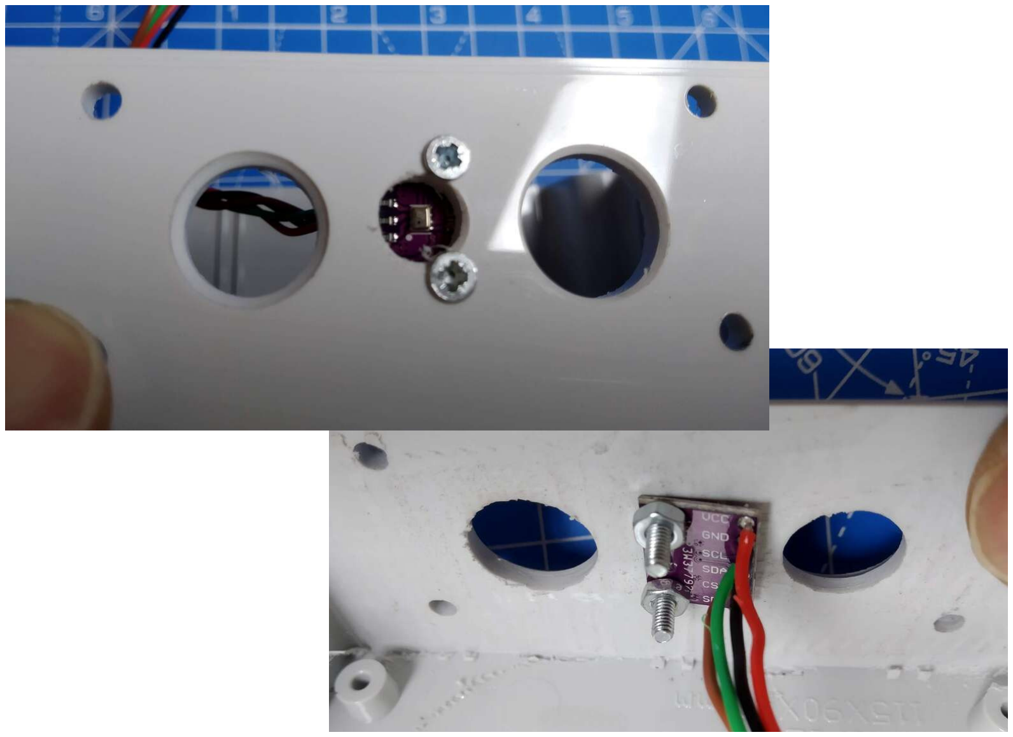
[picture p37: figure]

| Cut the piece of mesh to a size that covers the larger round and the middle rectangular hole.

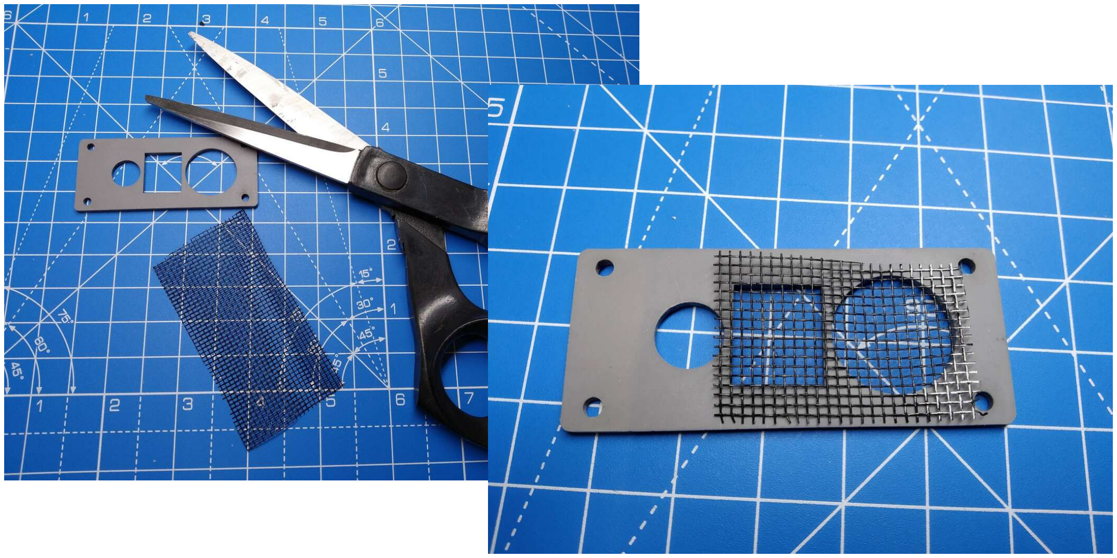
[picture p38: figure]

Step: 8 Add mesh, gasket and sensor plate

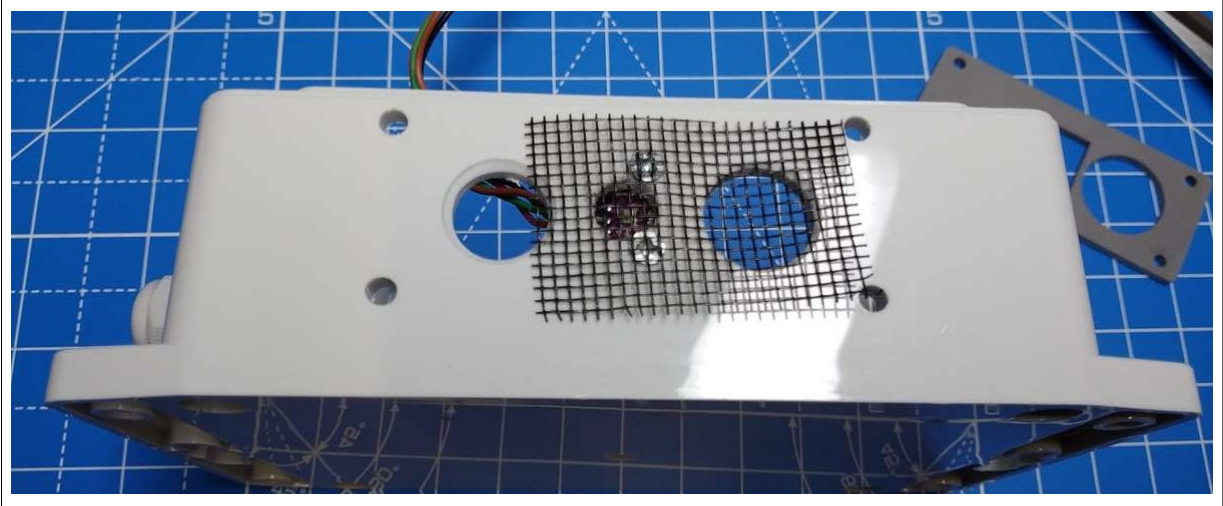
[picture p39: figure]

The mesh is held in place with
the rubber gasket and the
plastic outer plate.

Fit the mesh first, then the rubber gasket, then the 3mm acrylic output plate.

Use the 4 x M3 12mm screws and nuts to hold these in place onto the enclosure.

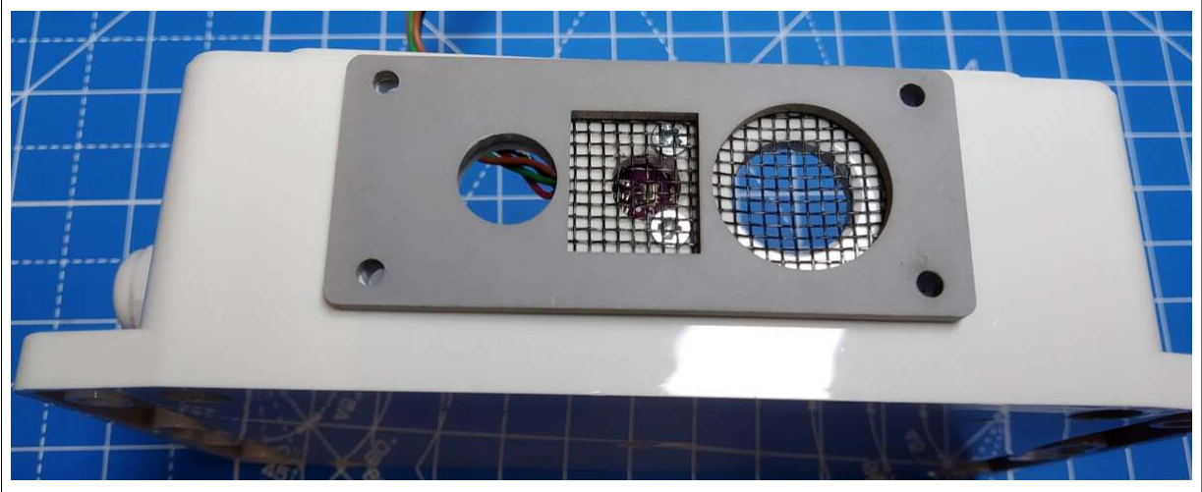
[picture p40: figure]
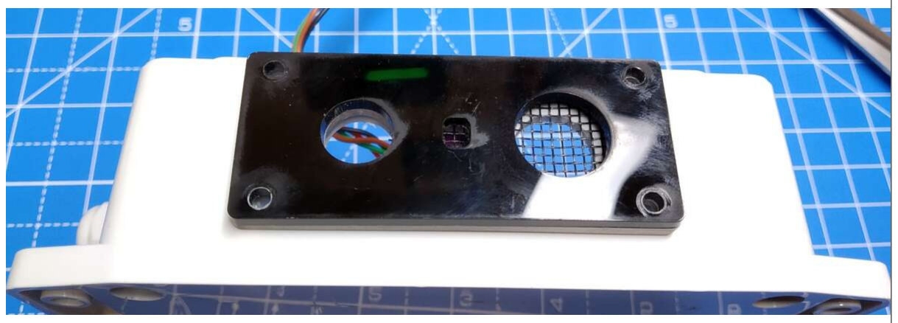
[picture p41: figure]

Step: 9 Mount baseplate into enclosure. Put the USB power cable through the compression gland, with the power terminals through into the enclosure. It’s easiest to add the USB lead now, or else it’s more difficult with the sensor/baseplate in place.
Fold the USB cable out of the way.

Fit the baseplate (with sensor and PCB) into the enclosure.
Use the 4 x self-tapping screws to hold the baseplate to the base of the enclosure.

I only use two of the self-tapping screws, as that is enough to hold the baseplate.
Ensure no cables are pinched or trapped.

Step: 10 Add the sensor tube The yellow plastic tube
is used as the intake for
the sensor. The tube is
mounted through the
smaller round hole on
the outer sensor plate
through and onto the
round intake for the
SDS011.

To make this a bit
easier, warm the yellow
tube in some boiling
water for a few minutes.
Warning: Take care!
This can be very hot!

Push the intake tube
through the smaller
hole and onto the
intake for the SDS011
sensor. You may need
to rotate slightly as you
push. This will be quite
a tight fit.

Step: 11 | Wire up power supply
| Ensure the cables fit into the enclosure. Wire up the USB power supply cable into the unit, with the red wire into the “+5V” screw terminal and the black wire into the “GND” terminal. If you plug the other end into the USB power supply unit then the blue light on the NodeMCU should briefly flash.


Step: 12 | Fit lid to enclosure
The lid needs the sealing strip mounted around the lid. Then fit the 4 x enclosure screws through the lid holes and close the unit up.
Step: 13 | Build is finished!


| Have a nice cup of tea.

Set-Up Instructions:


Step: 2 Register the sensor with sensor.community

Go to: hCps://devices.sensor.community/

You will need to register an account with this site.

Then click on: “My Sensors”
The click on “Register a new Sensor”

Follow the sensor registraon page – you will need the device ID you wrote down in the previous step.

Change the hardware configuraon so that the first sensor is the SDS011 (on pin 1) and the BME280 (on pin 11). The pin number change automacally when you click on the correct sensor.

Enter the locaon and any other details required and then “Save seLngs”

You can then check under your “My Sensors” list to check it is there.
Wait at least 30mins (or more!) and then re-check the “My Sensors” list.

Click on ‘Data’ and you should be able to see the latest data that has been uploaded.


This project full build, PCB and instrucons can be found here:
hps://github.com/curiouselectric/airQualitySensor

Contact details:

We would like you to be happy with this kit. If you are not happy for any reason then please contact us and we will help to sort it out.

Please email hello@curiouselectric.co.uk with any questions or comments.
Please tweet us at @curiouselectric

If any parts are missing from your kit then please email hello@curiouselectric.co.uk with details and, if possible, when and where the kit was purchased.

More technical information can be found via www.curiouselectric.co.uk

This kit has been designed and produced by:
The Curious Electric Company hello@curiouselectric.co.uk www.curiouselectric.co.uk

History

This kit is based upon lots of work by others especially:
- hCps://sensor.community/en/
- hCps://github.com/CivicLabsBelgium/influencair-pcb
- hCps://github.com/Naesstrom/Airrohr-kit

Circuit Schematic


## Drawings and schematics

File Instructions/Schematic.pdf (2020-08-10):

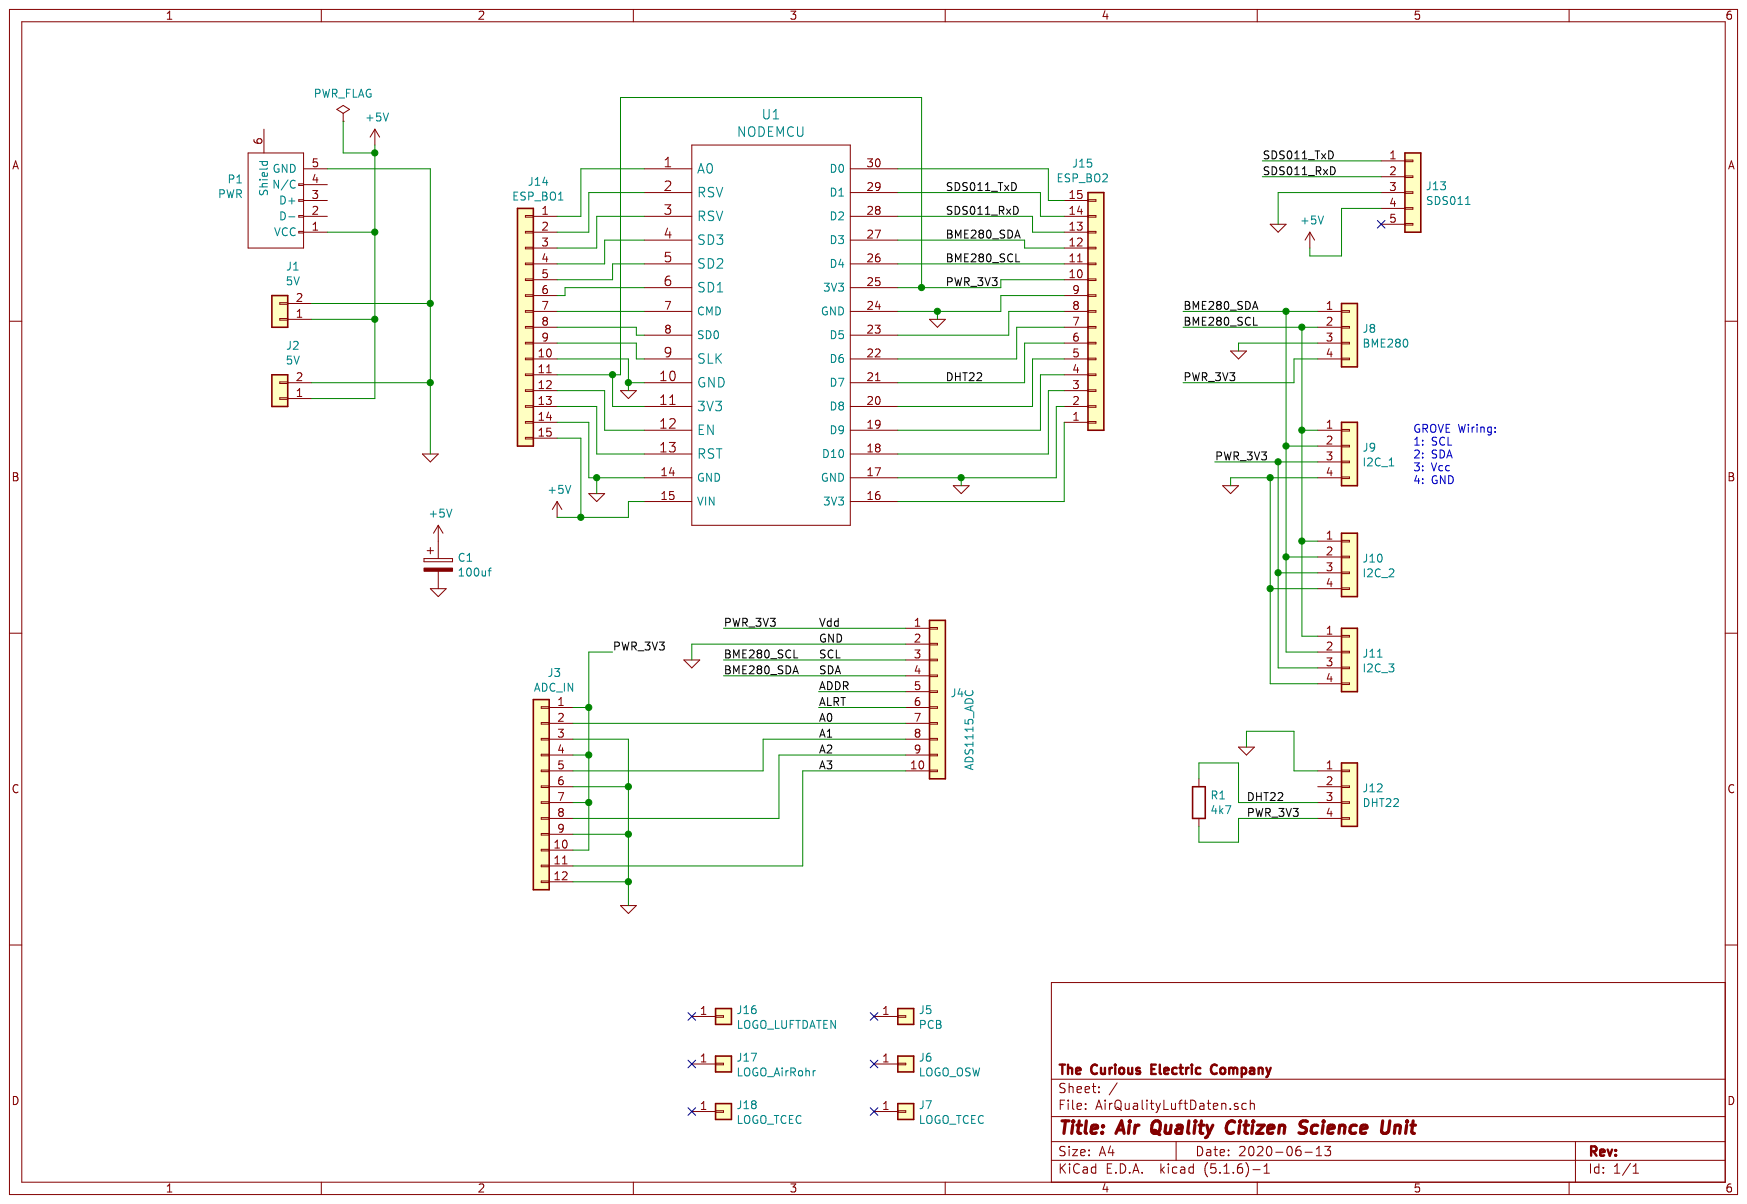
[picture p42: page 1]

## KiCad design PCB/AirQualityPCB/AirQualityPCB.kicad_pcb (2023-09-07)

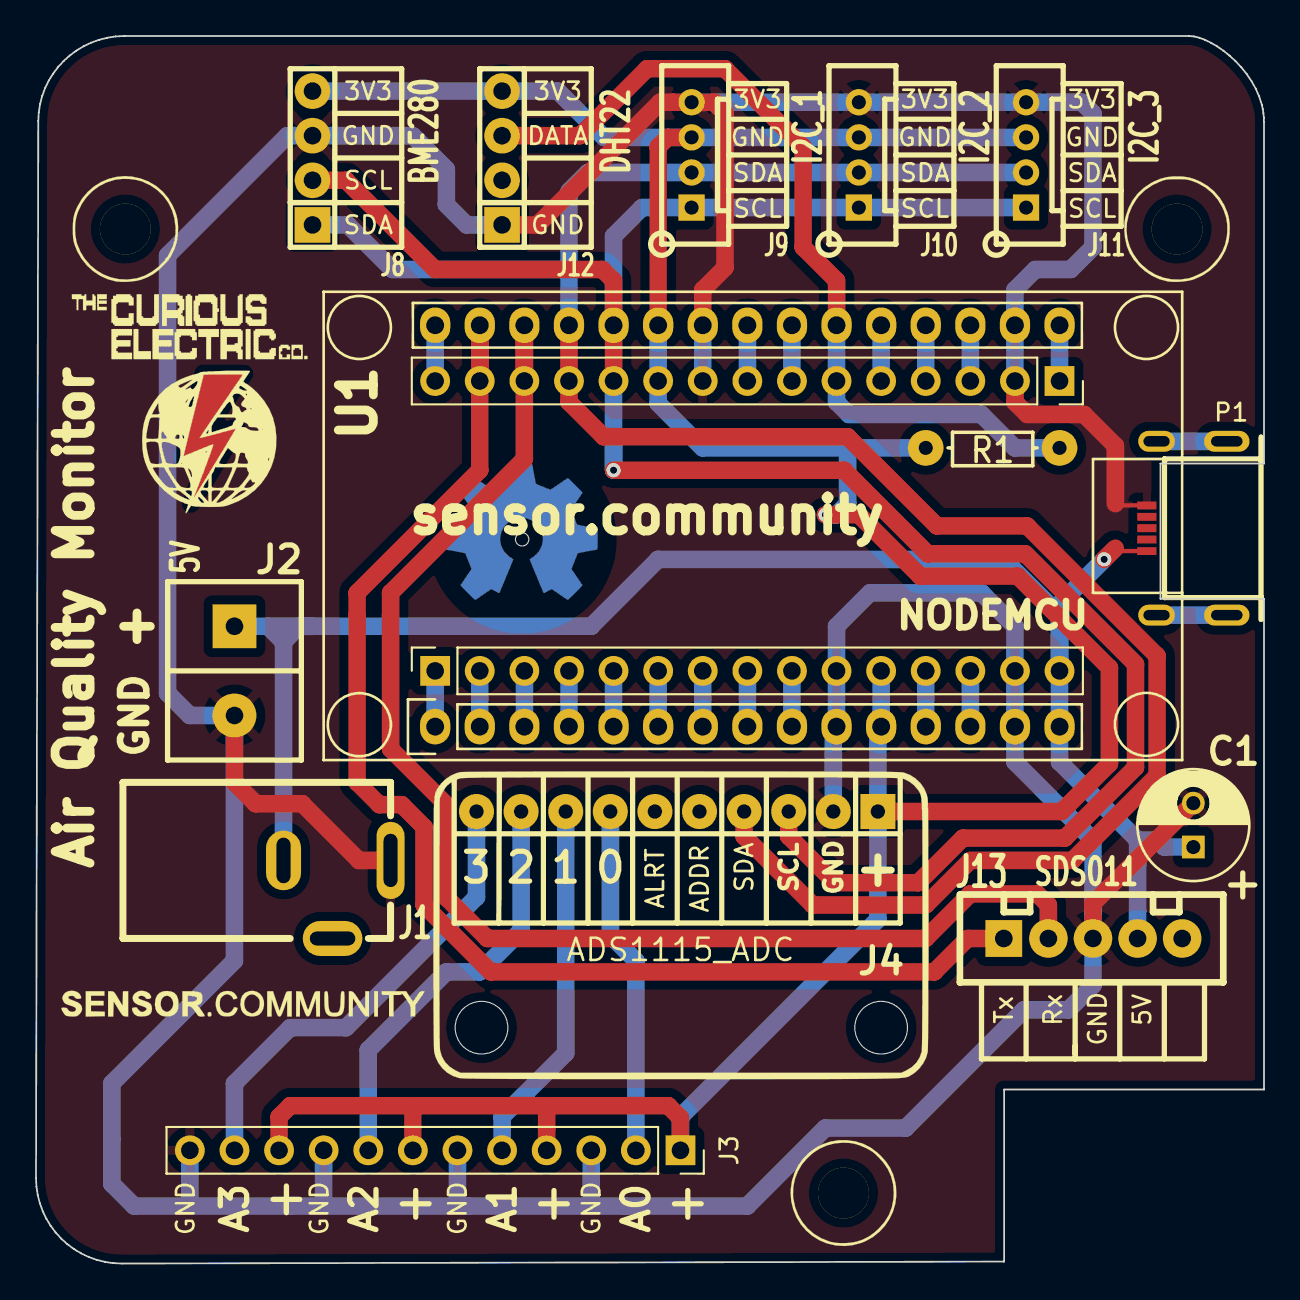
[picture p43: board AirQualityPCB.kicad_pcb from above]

Board: 2 copper layers, 69.9 x 69.9 mm, 21 parts (1 on the bottom side), 30 nets.

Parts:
C1: 100uf; C_Radial_D6.3_L11.2_P2.5
J1: 5V; DC_Power_2_1
J2: 5V; SIL-2_screw_terminal
J3: ADC_IN; PinSocket_1x12_P2.54mm_Vertical_Labelled
J4: ADS1115_ADC; ADAFRUIT_ADS1115
J5: PCB; PCB_LuftDaten_70x70
J6: LOGO_OSW; OSHW_logo_small_back
J7: LOGO_TCEC; TCEC_Words_13mm
J8: BME280; SIL-4_large_pad_BME280
J9: I2C_1; SIL-4_Grove_Labelled
J10: I2C_2; SIL-4_Grove_Labelled
J11: I2C_3; SIL-4_Grove_Labelled
J12: DHT22; SIL-4_large_pad_DHT22
J13: SDS011; SIL-5_JST_5WAY_labelled
J14: ESP_BO1; PinSocket_1x15_P2.54mm_Vertical
J15: ESP_BO2; PinSocket_1x15_P2.54mm_Vertical
J16: LOGO_LUFTDATEN; sensorcommunity
J18: LOGO_TCEC; 2019_011_16_CuriousElectricCompany_Logo_Round_Logo_No_words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
P1: PWR; USB_Micro-B_MOLEX_47642-0001
R1: 4k7; TH_Resistor_1
U1: NODEMCU; NodeMCU_Amica_R2_FSILK

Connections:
+5V: C1.1, J1.1, J2.1, J13.4, J14.15, P1.1 (VCC), U1.15 (VIN)
/A0: J3.2, J4.7
/A1: J3.5, J4.8
/A2: J3.8, J4.9
/A3: J3.11, J4.10
/BME280_SCL: J4.3, J8.2, J9.1, J10.1, J11.1, J15.11, U1.26 (D4)
/BME280_SDA: J4.4, J8.1, J9.2, J10.2, J11.2, J15.12, U1.27 (D3)
/DHT22: J12.3, J15.6, R1.1, U1.21 (D7)
/PWR_3V3: J3.1, J3.4, J3.7, J3.10, J4.1, J8.4, J9.3, J10.3, J11.3, J12.4, J14.11, J15.10, R1.2, U1.11 (3V3), U1.25 (3V3)
/SDS011_RxD: J13.2, J15.13, U1.28 (D2)
/SDS011_TxD: J13.1, J15.14, U1.29 (D1)
GND: C1.2, J1.2, J2.2, J3.3, J3.6, J3.9, J3.12, J4.2, J8.3, J9.4, J10.4, J11.4, J12.1, J13.3, J14.10, J14.14, J15.2, J15.9, P1.5 (GND), U1.10 (GND), U1.14 (GND), U1.17 (GND), U1.24 (GND)
unnamed: J14.1, U1.1 (A0)
unnamed: J14.2, U1.2 (RSV)
unnamed: J14.3, U1.3 (RSV)
unnamed: J14.4, U1.4 (SD3)
unnamed: J14.5, U1.5 (SD2)
unnamed: J14.6, U1.6 (SD1)
unnamed: J14.7, U1.7 (CMD)
unnamed: J14.8, U1.8 (SD0)
unnamed: J14.9, U1.9 (SLK)
unnamed: J14.12, U1.12 (EN)
unnamed: J14.13, U1.13 (RST)
unnamed: J15.1, U1.16 (3V3)
unnamed: J15.3, U1.18 (D10)
unnamed: J15.4, U1.19 (D9)
unnamed: J15.5, U1.20 (D8)
unnamed: J15.7, U1.22 (D6)
unnamed: J15.8, U1.23 (D5)
unnamed: J15.15, U1.30 (D0)

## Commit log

2020-06-14 Added PCB design and Hardware - initial commit
    [AirQualityLuftDaten.kicad_pcb, AirQualityLuftDaten.sch]
2020-08-10 Updated PCB and baseplate files
    [AirQualityLuftDaten-B_Cu.gbr, AirQualityLuftDaten-B_Mask.gbr, AirQualityLuftDaten-B_Paste.gbr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]
2020-08-10 Added Schematic and BOM
    [AirQualityUnit_BOM.csv, BOM.csv]
2023-09-07 Updated PCB and instructions. Removed old names and links
    [AirQualityLuftDaten-B_Cu.gbr, AirQualityLuftDaten-B_Mask.gbr, AirQualityLuftDaten-B_Paste.gbr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]
